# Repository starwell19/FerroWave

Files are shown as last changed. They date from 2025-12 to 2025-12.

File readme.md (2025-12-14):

# FerroWave

Audio-reactive **ferrofluid visualizer** built on **ESP32-A1S (ES8388)**.  
Streams Bluetooth audio (A2DP) or AUX input into the on-board codec, extracts live envelopes, and drives:

* a **coil + MOSFET trigger module** (PWM on GPIO 22) for ferrofluid motion
* a **WS2812B LED ring** (GPIO 23) for synced visuals
* **Six onboard buttons** for live preset control (no computer needed!)

> Created by **Makarov87** and **crowdfunded by the MakerWorld community**.  

**Crowdfunding Campaign:** https://makerworld.com/en/crowdfunding/70-ferrowave

---

## Acknowledgments

**This project was made possible by the MakerWorld community!**

FerroWave was successfully crowdfunded on MakerWorld, and it would not exist without the support, belief, and contributions of backers and makers from around the world.

**Special thanks to:**
- All MakerWorld backers who supported this campaign
- The MakerWorld platform for enabling maker-driven innovation
- Every contributor who helped bring this vision to life
- The open-source community for incredible libraries and tools

**Your support made this dream a reality. Thank you!** 🙏

---

## Project Status (AUX + Button Control Edition)

This repo reflects the **latest "AUX + Button Control Edition"** firmware with the finalized hardware layout.

**What's new in this version:**

* **AUX Input Support**: Auto-detects when 3.5mm cable is plugged in and switches from Bluetooth
* **Physical Button Controls**: Six onboard buttons for live control without serial/computer
  + Cycle through magnet modes (8 presets)
  + Cycle through LED effects (10 modes)
  + Switch between EQ presets (8 audio profiles)
* **Dual Input**: Seamlessly switch between Bluetooth and AUX input
* **Non-blocking performance**: Fixed audio stuttering issues for smooth playback

**Previous improvements:**

* Switched to **4x18650 battery pack** with breadboard power distribution:
  + Portable, cordless operation
  + Clean 5V rail for all components
  + 1-1.5 hours runtime typical
  + Simple, no voltage converters needed
* Low-side **MOSFET trigger module** (AOD4184-style):
  + Built-in flyback diode + status LED
  + 3.3 V logic input, 5V coil output
  + Much more maker-friendly than raw MOSFET wiring
* Finalized **pinout** to avoid conflicts with ES8388 codec and onboard buttons:
  + GPIO 22 → **MOSFET gate** (coil PWM)
  + GPIO 23 → **WS2812B LED DIN**
  + ES8388 on standard I²S pins (27 / 25 / 26 / 35 / 0)

---

## Table of Contents

* [Features](#features)
* [Hardware](#hardware)
* [Button Controls](#button-controls)
* [Wiring](#wiring-quick-reference)
* [Power](#power-4x18650-battery-system)
* [Pinout](#pinout)
* [Firmware Setup](#firmware-setup-arduino-ide)
* [Required Libraries](#required-libraries)
* [Build & Upload](#build--upload)
* [Serial Commands](#serial-tuning-panel)
* [How to Use](#how-to-use)
* [Troubleshooting](#troubleshooting)
* [Contributing](#contributing)
* [License](#license)

---

## Features

* **Dual Input Sources**:
  + **Bluetooth A2DP sink** for wireless audio
  + **AUX/Line-In** with auto-detection (switches when cable is plugged in)
* **Six Physical Buttons** for standalone operation:
  + Cycle magnet modes (up/down)
  + Cycle LED effects (up/down)
  + Switch EQ presets (up/down)
* **8 Magnet Behavior Modes**:
  + SMOOTH, SPIKE, BOUNCE, CHAOS, PULSE, WAVE, TREMOLO, BREATH
* **10 LED Visual Effects**:
  + Rainbow, Spectrum, VU-Meter, Pulse, Bass Glow, Fire, Ocean, Strobe, Chase, Sparkle
* **8 EQ Presets**:
  + Flat, Bass Boost, Treble, Vocal, Rock, Electronic, Jazz, Classical
* **Magnet control** via LEDC **PWM** on GPIO 22 with:
  + Adjustable frequency (1-5000 Hz)
  + Tunable duty window and sensitivity
  + Real-time envelope followers
* **Serial tuning panel** for advanced control:
  + Live parameter adjustment
  + Test pulses and diagnostics
  + Status readouts
* Designed to be **stable on ESP32 core 2.0.14+**

---

## Hardware

### Required Components

* **ESP32-A1S / ESP32-Audio-Kit v2.2** (with **ES8388** codec)
* **WS2812B LED ring** (24 LEDs recommended)
* **Low-side MOSFET trigger module** (AOD4184 or similar)
* **Electromagnet** (5V, 1-2A)
* **4x18650 Battery Pack** with 5V output
* **Breadboard Power Module**
* **Ferrofluid display container**

See [docs/BOM.md](docs/BOM.md) for complete bill of materials.

---

## Button Controls

| Button | GPIO | Function | Action |
|---|---|---|---|
| **Button 1** | GPIO 36 | Magnet Mode | Cycle UP through 8 modes |
| **Button 2** | GPIO 39 | Magnet Mode | Cycle DOWN through 8 modes |
| **Button 3** | GPIO 34 | LED Effect | Cycle UP through 10 effects |
| **Button 4** | GPIO 35 | LED Effect | Cycle DOWN through 10 effects |
| **Button 5** | GPIO 32 | EQ Preset | Cycle UP through 8 presets |
| **Button 6** | GPIO 33 | EQ Preset | Cycle DOWN through 8 presets |

---

## Wiring (quick reference)

```
4x18650 Battery Pack (5V Output)
         |
    Power Switch
         |
  Breadboard Power Module
    (+ and - rails)
         |
         ├──> ESP32-A1S (5V + GND)
         ├──> LED Ring (5V + GND)
         └──> Electromagnet + (5V)

LED Ring DIN ──> GPIO 23 (through 330Ω resistor)
ESP32 GPIO 22 ──> MOSFET Gate
```

See [docs/WIRING.md](docs/WIRING.md) for complete instructions.

---

## Power (4x18650 Battery System)

* **Portable operation** with rechargeable batteries
* **1-1.5 hours** typical runtime
* **2-4A** typical draw, up to 5A peak
* Uses quality protected 18650 cells (Samsung, LG, Sony, Panasonic)

---

## Pinout

**Control:**
* GPIO 22 → MOSFET gate (PWM)
* GPIO 23 → LED ring DIN

**Buttons:**
* GPIO 36, 39, 34, 35, 32, 33 (built-in)

**I²S Audio:**
* GPIO 27 → BCK
* GPIO 25 → WS
* GPIO 26 → DATA_OUT

---

## Firmware Setup (Arduino IDE)

1. Install **ESP32 board support** (v2.0.14+)
2. Select **"ESP32 Dev Module"**
3. Install required libraries (see below)
4. Upload firmware
5. Connect via Bluetooth or AUX

---

## Required Libraries

Install via Arduino Library Manager:

1. **AudioTools** by pschatzmann
2. **ESP32-A2DP** by pschatzmann
3. **Adafruit NeoPixel** by Adafruit

See [docs/LIBRARIES.md](docs/LIBRARIES.md) for detailed installation.

---

## Build & Upload

1. Clone repository
2. Open `.ino` file in Arduino IDE
3. Select COM port
4. Press **Upload**
5. Open Serial Monitor (115200 baud)
6. Connect and play music!

---

## Serial Tuning Panel

**Magnet Modes (1-8):**
```
1=SMOOTH  2=SPIKE  3=BOUNCE  4=CHAOS
5=PULSE   6=WAVE   7=TREMOLO 8=BREATH
```

**LED Modes (c1-c10):**
```
c1=Rainbow  c2=Spectrum  c3=Pulse    c4=VU-Meter  c5=Bass Glow
c6=Fire     c7=Ocean     c8=Strobe   c9=Chase     c10=Sparkle
```

**Parameters:**
```
f<num> = PWM frequency    s<num> = Sensitivity
a<num> = Attack speed     r<num> = Release speed
d<num> = Max duty         b<num> = Base duty
p<num> = Spike intensity  l<num> = LED brightness
v<num> = Volume
```

**Utilities:**
```
? = Show settings    t = Test pulse
m = List modes       n = List LED modes
aux = Switch to AUX  bt = Switch to Bluetooth
```

See [commands.md](commands.md) for complete reference.

---

## How to Use

### Standalone (No Computer)
1. Power on
2. Connect Bluetooth or plug AUX cable
3. Play music
4. Use buttons to control presets

### Advanced (Serial Monitor)
1. Connect USB
2. Open Serial Monitor (115200 baud)
3. Use commands for fine tuning
4. Type `?` for current settings

---

## Troubleshooting

**No power?** Check battery charge and connections  
**No audio?** Verify Bluetooth pairing or AUX cable  
**Coil not working?** Test with `t` command  
**LEDs dark?** Try `l255` and check GPIO 23

See [docs/TROUBLESHOOTING.md](docs/TROUBLESHOOTING.md) for complete guide.

---

## Contributing

Contributions welcome! See [CONTRIBUTING.md](CONTRIBUTING.md) for guidelines.

**This project was crowdfunded by the MakerWorld community!**

---

## Community & Support

* **Issues**: [GitHub Issues](https://github.com/matoslav/FerroWave/issues)
* **Discussions**: [GitHub Discussions](https://github.com/matoslav/FerroWave/discussions)
* **MakerWorld**: https://makerworld.com/en/crowdfunding/70-ferrowave

If you want to support me and my FerroWave development, you can buy me a coffee at: https://ko-fi.com/makarov87

---

## Credits

**Created by**: Makarov87  
**Crowdfunded by**: MakerWorld Community

**Libraries:**
* [AudioTools](https://github.com/pschatzmann/arduino-audio-tools) by pschatzmann
* [ESP32-A2DP](https://github.com/pschatzmann/ESP32-A2DP) by pschatzmann
* [Adafruit NeoPixel](https://github.com/adafruit/Adafruit_NeoPixel) by Adafruit

**Special Thanks:**
* All MakerWorld backers
* Open-source Arduino and ESP32 communities
* Everyone who contributed ideas and feedback

---

## License

MIT License - See [LICENSE](LICENSE) file.

**Author**: Makarov87  
**Crowdfunded by**: MakerWorld Community

When using or modifying FerroWave:
- Credit Makarov87
- Link to https://github.com/matoslav/FerroWave
- Acknowledge MakerWorld crowdfunding

---

**Created by Makarov87**  
**Crowdfunded by the MakerWorld Community**  
**Built with ❤️ and ferrofluid**

Thank you to all MakerWorld backers! 🙏

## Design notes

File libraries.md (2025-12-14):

# FerroWave DIY Build Guide
## Required Libraries & Installation

### Hardware Requirements
- **ESP32-A1S Audio Kit v2.2** (with ES8388 codec)
- **5V Electromagnet** (controlled via MOSFET)
- **WS2812B LED Ring** (24 LEDs)
- **MOSFET** (e.g., IRLZ44N or similar logic-level N-channel)
- **330Ω Resistor** (for LED data line)
- **Ferrofluid** in display container
- Power supply (5V for LEDs and magnet)

---

## Arduino IDE Setup

### 1. ESP32 Board Support
Install ESP32 board support in Arduino IDE:

**Via Board Manager:**
1. Open Arduino IDE
2. Go to `File` → `Preferences`
3. Add to "Additional Board URLs":
   ```
   https://espressif.github.io/arduino-esp32/package_esp32_index.json
   ```
4. Go to `Tools` → `Board` → `Boards Manager`
5. Search for "ESP32" and install **"esp32" by Espressif Systems**
6. Select Board: `Tools` → `Board` → `ESP32 Arduino` → `ESP32 Dev Module`

---

## Required Libraries

### 1. **AudioTools** (by Phil Schatzmann)
**Primary audio processing library**

**Installation:**
- Arduino IDE: `Sketch` → `Include Library` → `Manage Libraries`
- Search: "AudioTools"
- Install: **"AudioTools" by pschatzmann**
- Version: Latest (tested with v0.9.x)

**GitHub:** https://github.com/pschatzmann/arduino-audio-tools

**What it does:**
- Handles I2S audio streams
- Provides AudioBoardStream for ES8388 codec
- Ring buffer for audio processing
- Multi-output routing (Bluetooth + processing)

---

### 2. **ESP32-A2DP** (by Phil Schatzmann)
**Bluetooth A2DP audio sink**

**Installation:**
- Arduino IDE: `Sketch` → `Include Library` → `Manage Libraries`
- Search: "ESP32-A2DP"
- Install: **"ESP32-A2DP" by pschatzmann**
- Version: Latest (tested with v1.7.x)

**GitHub:** https://github.com/pschatzmann/ESP32-A2DP

**What it does:**
- Enables Bluetooth audio receiver functionality
- A2DP profile support (wireless audio streaming)
- Integrates with AudioTools for audio routing

---

### 3. **Adafruit NeoPixel**
**WS2812B LED control**

**Installation:**
- Arduino IDE: `Sketch` → `Include Library` → `Manage Libraries`
- Search: "Adafruit NeoPixel"
- Install: **"Adafruit NeoPixel" by Adafruit**
- Version: Latest (tested with v1.11.x)

**GitHub:** https://github.com/adafruit/Adafruit_NeoPixel

**What it does:**
- Controls WS2812B addressable RGB LEDs
- Handles color calculations and LED timing
- Provides easy color and brightness control

---

## Complete Library Installation Summary

### Option 1: Arduino Library Manager (Recommended)
```
1. Sketch → Include Library → Manage Libraries
2. Search and install each:
   - "AudioTools" by pschatzmann
   - "ESP32-A2DP" by pschatzmann
   - "Adafruit NeoPixel" by Adafruit
```

### Option 2: Manual Installation (Advanced)
Clone repositories into your Arduino `libraries` folder:

```bash
cd ~/Documents/Arduino/libraries/

# AudioTools
git clone https://github.com/pschatzmann/arduino-audio-tools.git

# ESP32-A2DP
git clone https://github.com/pschatzmann/ESP32-A2DP.git

# Adafruit NeoPixel
git clone https://github.com/adafruit/Adafruit_NeoPixel.git
```

Then restart Arduino IDE.

---

## Wiring Diagram

### ESP32-A1S Connections

**Electromagnet (via MOSFET):**
- MOSFET Gate → GPIO 22
- MOSFET Drain → Electromagnet (-)
- MOSFET Source → GND
- Electromagnet (+) → 5V Power Supply

**LED Ring (WS2812B):**
- LED DIN → GPIO 23 (through 330Ω resistor)
- LED VCC → 5V
- LED GND → GND

**Onboard Buttons (ESP32-A1S):**
- Button 1: GPIO 36 (Magnet Mode ↑)
- Button 2: GPIO 39 (Magnet Mode ↓)
- Button 3: GPIO 34 (LED Mode ↑)
- Button 4: GPIO 35 (LED Mode ↓)
- Button 5: GPIO 32 (EQ Preset ↑)
- Button 6: GPIO 33 (EQ Preset ↓)

**I2S Audio (Pre-wired on ESP32-A1S):**
- BCK: GPIO 27
- WS: GPIO 25
- DATA OUT: GPIO 26
- DATA IN (AUX): GPIO 35
- MCLK: GPIO 0

---

## Upload Settings

**Board Settings in Arduino IDE:**
```
Board: "ESP32 Dev Module"
Upload Speed: 921600
CPU Frequency: 240MHz
Flash Frequency: 80MHz
Flash Mode: QIO
Flash Size: 4MB (32Mb)
Partition Scheme: "Default 4MB with spiffs"
Core Debug Level: "None"
PSRAM: "Disabled"
```

**Port:** Select your ESP32's COM/USB port

---

## Compilation Notes

### Expected Memory Usage
- Sketch uses approximately **~65-75%** of program storage
- Global variables use approximately **~25-30%** of dynamic memory
- Uses ESP32 dual-core capabilities for audio processing

### Common Compilation Issues

**1. "AudioSource is ambiguous"**
- Fixed in code (renamed enum to `InputSource`)
- Caused by naming conflict with AudioTools library

**2. Missing library errors**
- Ensure all three libraries are installed
- Restart Arduino IDE after installation

**3. "Bluetooth: Cannot allocate memory"**
- Set partition scheme to "Default 4MB with spiffs"
- Ensure no other large libraries are included

---

## First Boot Checklist

1. **Serial Monitor** (115200 baud)
   - Should show startup banner
   - Lists all button controls
   - Shows current settings

2. **LED Ring Test**
   - Blue startup animation on power-up
   - Should respond to audio input

3. **Bluetooth Pairing**
   - Device name: "FerroWave_AUX"
   - Should appear in Bluetooth device list
   - No pairing code required

4. **Test Commands**
   - Type `?` in Serial Monitor to see settings
   - Type `t` to test electromagnet pulse
   - Type `m` to list magnet modes

---

## Troubleshooting

### No Audio Output
- Check I2S wiring (BCK, WS, DATA pins)
- Verify AudioBoardStream configuration
- Ensure ES8388 codec is properly initialized

### LEDs Not Working
- Verify LED power (5V, GND)
- Check data pin (GPIO 23) connection
- Ensure 330Ω resistor is in place
- Try reducing LED brightness: `l50` in serial

### Electromagnet Not Responding
- Check MOSFET wiring
- Verify GPIO 22 connection
- Test with `t` command in serial monitor
- Check power supply capacity

### Bluetooth Won't Connect
- Restart ESP32
- Ensure no other device is connected
- Check if Bluetooth is enabled on source device
- Try forgetting device and re-pairing

---

## Power Requirements

- **ESP32-A1S Board:** ~500mA (via USB or 5V)
- **LED Ring (24 LEDs):** Up to 1.4A at full brightness white
- **Electromagnet:** 500mA - 2A depending on coil

**Recommended:** 5V 3A+ power supply for stable operation

---

## Additional Resources

- **AudioTools Documentation:** https://github.com/pschatzmann/arduino-audio-tools/wiki
- **ESP32-A2DP Examples:** https://github.com/pschatzmann/ESP32-A2DP/tree/main/examples
- **NeoPixel Guide:** https://learn.adafruit.com/adafruit-neopixel-uberguide

---

## License & Credits

- **FerroWave:** DIY ferrofluid visualizer project
- **Libraries:** See individual library licenses
  - AudioTools: GPL-3.0
  - ESP32-A2DP: Apache-2.0
  - Adafruit NeoPixel: LGPL-3.0

---

**Version:** 1.0 (AUX + Button Control Edition)  
**Last Updated:** December 2024

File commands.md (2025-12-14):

# FerroWave Serial Commands Reference

Complete command reference for controlling FerroWave via Serial Monitor (115200 baud).

> **Note:** Physical buttons provide quick access to presets. Serial commands are for advanced tuning and diagnostics.

---

## Quick Reference

| Command | Function | Example |
|---|---|---|
| `1-8` | Select magnet mode | `3` |
| `c1-c10` | Select LED mode | `c7` |
| `f<num>` | Set PWM frequency | `f500` |
| `s<num>` | Set sensitivity | `s120` |
| `a<num>` | Set attack speed | `a80` |
| `r<num>` | Set release speed | `r40` |
| `d<num>` | Set max duty | `d85` |
| `b<num>` | Set base duty | `b20` |
| `p<num>` | Set spike intensity | `p70` |
| `l<num>` | Set LED brightness | `l150` |
| `v<num>` | Set volume | `v75` |
| `aux` | Switch to AUX input | `aux` |
| `bt` | Switch to Bluetooth | `bt` |
| `?` | Show current settings | `?` |
| `t` | Test pulse | `t` |
| `m` | List magnet modes | `m` |
| `n` | List LED modes | `n` |

---

## Magnet Mode Selection

**Syntax:** Single digit `1-8`

| Command | Mode | Description | Characteristics |
|---|---|---|---|
| `1` | SMOOTH | Gentle flowing waves | Slow, graceful, relaxed |
| `2` | SPIKE | Sharp transients | Emphasizes beats, spiky |
| `3` | BOUNCE | Rhythmic pumping | Follows groove, bouncy |
| `4` | CHAOS | Aggressive random | Unpredictable, maximum power |
| `5` | PULSE | Beat-synced pulses | Distinct on/off, percussive |
| `6` | WAVE | Building surges | Slow accumulation, dramatic |
| `7` | TREMOLO | Rapid flutter | Vibrato effect, rapid |
| `8` | BREATH | Meditative breathing | Very slow, calming |

**Example:**
```
> 2
Mode -> SPIKE
```

---

## LED Mode Selection

**Syntax:** `c<number>` where number is 1-10

| Command | Mode | Description | Effect Type |
|---|---|---|---|
| `c1` | Rainbow | Spinning rainbow wheel | Color cycle |
| `c2` | Spectrum | Bar graph analyzer | Audio reactive |
| `c3` | Pulse | Blue breathing effect | Single color pulse |
| `c4` | VU-Meter | Center-split meter | Audio level |
| `c5` | Bass Glow | Red bass intensity | Audio reactive |
| `c6` | Fire | Flickering flames | Animated |
| `c7` | Ocean | Blue-green waves | Animated |
| `c8` | Strobe | White flash on peaks | Audio reactive |
| `c9` | Chase | Three colored dots | Animated |
| `c10` | Sparkle | Random twinkling | Animated |

**Example:**
```
> c7
LED mode -> Ocean
```

---

## Tuning Parameters

### PWM Frequency (`f`)

**Syntax:** `f<number>`  
**Range:** 1-5000 Hz  
**Default:** 4 Hz

Controls how fast the electromagnet pulses.

**Recommended ranges:**
- `f2-f10`: Slow, visible pulsing (dramatic movement)
- `f50-f500`: Mid-range smooth control
- `f1000-f2000`: Very fast, near-continuous force

**Examples:**
```
> f4
PWM frequency -> 4.0 Hz

> f500
PWM frequency -> 500.0 Hz

> f1000
PWM frequency -> 1000.0 Hz
```

---

### Sensitivity (`s`)

**Syntax:** `s<number>`  
**Range:** 0-200%  
**Default:** 100%

Controls how strongly audio input affects the magnet.

**Guide:**
- `s50`: Subtle, requires loud music
- `s100`: Default, balanced
- `s150`: Sensitive, reacts to small changes
- `s200`: Maximum sensitivity

**Examples:**
```
> s120
Sensitivity -> 120%

> s80
Sensitivity -> 80%
```

---

### Attack Speed (`a`)

**Syntax:** `a<number>`  
**Range:** 0-100  
**Default:** 60

How fast the magnet responds to increasing audio levels.

**Guide:**
- `a10-a40`: Slow, smooth response
- `a50-a70`: Musical, natural
- `a80-a100`: Snappy, percussive

**Examples:**
```
> a85
Attack speed -> 85/100

> a30
Attack speed -> 30/100
```

---

### Release Speed (`r`)

**Syntax:** `r<number>`  
**Range:** 0-100  
**Default:** 30

How fast the magnet relaxes when audio decreases.

**Guide:**
- `r10-r30`: Slow decay, sustained
- `r40-r60`: Moderate release
- `r70-r100`: Fast drop, tight

**Examples:**
```
> r50
Release speed -> 50/100

> r20
Release speed -> 20/100
```

---

### Max Duty (`d`)

**Syntax:** `d<number>`  
**Range:** 10-100%  
**Default:** 80%

Maximum power ceiling for electromagnet (safety limit).

**Guide:**
- `d60-d80`: Safe, conservative
- `d85-d95`: Higher power (watch temperature)
- `d100`: Maximum (only with adequate cooling)

⚠️ **Warning:** Higher values generate more heat. Monitor coil temperature!

**Examples:**
```
> d75
Max duty -> 75%

> d90
Max duty -> 90%
```

---

### Base Duty (`b`)

**Syntax:** `b<number>`  
**Range:** 0-50%  
**Default:** 15%

Minimum always-on power (baseline magnetic field).

**Guide:**
- `b0`: Off when silent (dynamic range)
- `b10-b20`: Gentle constant field
- `b30-b50`: Strong baseline (less dynamic)

**Examples:**
```
> b20
Base duty -> 20%

> b5
Base duty -> 5%
```

---

### Spike Intensity (`p`)

**Syntax:** `p<number>`  
**Range:** 0-100  
**Default:** 50

Extra boost for SPIKE and transient-heavy modes.

**Guide:**
- `p30-p50`: Moderate emphasis
- `p60-p80`: Strong spikes
- `p90-p100`: Maximum aggression

**Examples:**
```
> p75
Spike intensity -> 75/100

> p40
Spike intensity -> 40/100
```

---

### LED Brightness (`l`)

**Syntax:** `l<number>`  
**Range:** 0-255  
**Default:** 100

LED ring brightness level.

**Guide:**
- `l50`: Dim (power saving)
- `l100`: Default
- `l150`: Bright
- `l255`: Maximum

**Examples:**
```
> l180
LED brightness -> 180/255

> l60
LED brightness -> 60/255
```

---

### Volume (`v`)

**Syntax:** `v<number>`  
**Range:** 0-100%  
**Default:** 80%

Audio output volume level.

**Examples:**
```
> v75
Volume -> 75%

> v90
Volume -> 90%
```

---

## Audio Source Control

### Switch to AUX Input

**Syntax:** `aux`

Manually switch to 3.5mm AUX line input.

```
> aux
Switching to AUX input...
AUX input active
```

---

### Switch to Bluetooth

**Syntax:** `bt`

Manually switch to Bluetooth A2DP input.

```
> bt
Switching to Bluetooth...
Bluetooth active
```

> **Note:** AUX input auto-switches when cable is detected. These commands allow manual override.

---

## Utility Commands

### Show Current Settings (`?`)

**Syntax:** `?`

Displays all current parameter values and modes.

```
> ?

========== CURRENT SETTINGS ==========
Audio Source:    Bluetooth
Magnet Mode:     SPIKE
PWM Frequency:   4.0 Hz
Sensitivity:     120%
Attack Speed:    85/100
Release Speed:   40/100
Max Duty:        80%
Base Duty:       15%
Spike Intensity: 75/100
Volume:          80%
EQ Preset:       Bass Boost
Bass EQ:         +6
Treble EQ:       -2
LED Brightness:  100/255
LED Mode:        Fire
======================================
```

---

### Test Pulse (`t`)

**Syntax:** `t`

Triggers a 2-second full-power test pulse with LED flash.

Useful for:
- Testing electromagnet wiring
- Verifying MOSFET functionality
- Checking power supply capacity

```
> t
TEST PULSE: 2 seconds at max...
Test complete.
```

---

### List Magnet Modes (`m`)

**Syntax:** `m`

Displays all available magnet modes.

```
> m

========== MAGNET MODES ==========
1 = SMOOTH  - Gentle flowing waves
2 = SPIKE   - Sharp transients, spiky
3 = BOUNCE  - Rhythmic pumping
4 = CHAOS   - Aggressive, unpredictable
5 = PULSE   - Distinct on/off beats
6 = WAVE    - Slow building surges
7 = TREMOLO - Rapid flutter effect
8 = BREATH  - Slow meditative breathing
==================================
```

---

### List LED Modes (`n`)

**Syntax:** `n`

Displays all available LED effects.

```
> n

========== LED MODES ==========
c1  = Rainbow spin
c2  = Spectrum analyzer
c3  = Pulse (blue)
c4  = VU-Meter
c5  = Bass glow (red)
c6  = Fire effect
c7  = Ocean waves
c8  = Strobe flash
c9  = Color chase
c10 = Sparkle
===============================
```

---

## Preset Recipes

### Quick-Start Presets

Copy and paste these command sequences for instant presets:

#### 🎉 Party Mode
```
2
c8
f4
s150
a90
r40
p80
l200
```

#### 🌊 Chill Mode
```
8
c7
f2
s60
a30
r20
l100
```

#### 💃 Dance Mode
```
3
c2
f10
s120
a80
r60
l150
```

#### 🔥 Fire Show
```
4
c6
f500
s140
a85
d90
l180
```

---

## Tips & Best Practices

### For Experimentation
1. Start with `?` to see current settings
2. Change one parameter at a time
3. Use `t` to verify electromagnet response
4. Watch Serial output for real-time feedback

### For Performance
1. Set your desired mode (`1-8`)
2. Set LED effect (`c1-c10`)
3. Fine-tune sensitivity (`s`) first
4. Adjust attack/release (`a`, `r`) for feel
5. Set PWM frequency (`f`) for desired motion style

### For Safety
1. Always start with `d80` or lower
2. Monitor coil temperature when increasing `d`
3. Use `b` to set a safe baseline
4. Test with `t` before live performance

---

## Troubleshooting Commands

### Magnet not responding?
```
> t          # Test pulse
> d90        # Increase max duty
> s150       # Increase sensitivity
> b20        # Add baseline field
```

### Too aggressive?
```
> s80        # Reduce sensitivity
> d70        # Lower power ceiling
> a40        # Slow attack
> r30        # Slow release
```

### LEDs too dim?
```
> l200       # Increase brightness
> c1         # Try rainbow (brightest)
```

### Audio source issues?
```
> aux        # Switch to AUX
> bt         # Switch to Bluetooth
> v80        # Adjust volume
```

---

**For physical button controls, see the main README.md**

---

*Part of the [FerroWave](https://github.com/matoslav/FerroWave) project by Makarov87*

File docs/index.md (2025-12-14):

# FerroWave Documentation

Welcome to the FerroWave documentation! This index will help you find the information you need.

**Project**: FerroWave - Audio-Reactive Ferrofluid Visualizer  
**Author**: Makarov87  
**Crowdfunded by**: [MakerWorld Community](https://makerworld.com/en/crowdfunding/70-ferrowave)  
**License**: MIT

---

## Quick Links

- **[Main Repository](https://github.com/matoslav/FerroWave)** - GitHub repository
- **[MakerWorld Campaign](https://makerworld.com/en/crowdfunding/70-ferrowave)** - Crowdfunding page
- **[Issues](https://github.com/matoslav/FerroWave/issues)** - Report bugs or request features
- **[Discussions](https://github.com/matoslav/FerroWave/discussions)** - Community discussion

---

## 📚 Documentation

### Getting Started

Start here if you're new to FerroWave:

1. **[README.md](../README.md)** - Project overview, features, and quick start
2. **[BOM.md](BOM.md)** - Complete bill of materials and shopping guide
3. **[LIBRARIES.md](LIBRARIES.md)** - Required Arduino libraries installation
4. **[WIRING.md](WIRING.md)** - Step-by-step wiring instructions

### Building & Programming

Follow these guides to build and program your FerroWave:

- **[WIRING.md](WIRING.md)** - Complete wiring guide with diagrams
  - Power system setup (4x18650 battery)
  - ESP32-A1S connections
  - Electromagnet circuit
  - LED ring wiring
  - Step-by-step assembly

- **[LIBRARIES.md](LIBRARIES.md)** - Library installation
  - Arduino IDE setup
  - ESP32 board support
  - Required libraries (AudioTools, ESP32-A2DP, NeoPixel)
  - Compilation settings

### Using FerroWave

Learn how to operate and customize:

- **[commands.md](../commands.md)** - Serial command reference
  - Magnet modes (1-8)
  - LED effects (c1-c10)
  - Tuning parameters
  - Audio source control
  - Preset recipes

- **[README.md](../README.md)** - Usage guide
  - Button controls
  - EQ presets
  - Recommended settings
  - Performance tips

### Troubleshooting & Support

Having issues? Check here:

- **[TROUBLESHOOTING.md](TROUBLESHOOTING.md)** - Comprehensive troubleshooting
  - Power issues
  - Compilation errors
  - Upload problems
  - Audio issues
  - Electromagnet problems
  - LED issues
  - Battery problems

### Contributing

Want to contribute to FerroWave?

- **[CONTRIBUTING.md](../CONTRIBUTING.md)** - Contribution guidelines
  - How to contribute
  - Code style guidelines
  - Development workflow
  - Community guidelines

- **[CHANGELOG.md](../CHANGELOG.md)** - Version history and roadmap

### Legal

- **[LICENSE](../LICENSE)** - MIT License with attribution requirements

---

## 📖 Document Overview

### Main Documents (Root Level)

| Document | Description | Audience |
|---|---|---|
| [README.md](../README.md) | Main project documentation | Everyone |
| [LICENSE](../LICENSE) | MIT License & attribution | Everyone |
| [CHANGELOG.md](../CHANGELOG.md) | Version history | Developers |
| [CONTRIBUTING.md](../CONTRIBUTING.md) | How to contribute | Contributors |
| [commands.md](../commands.md) | Serial command reference | Users |

### Documentation Folder (docs/)

| Document | Description | Audience |
|---|---|---|
| [BOM.md](BOM.md) | Bill of materials | Builders |
| [LIBRARIES.md](LIBRARIES.md) | Library installation | Builders |
| [WIRING.md](WIRING.md) | Wiring instructions | Builders |
| [TROUBLESHOOTING.md](TROUBLESHOOTING.md) | Problem solving | Users |
| [index.md](index.md) | This document | Everyone |

---

## 🚀 Quick Start Guide

### For First-Time Builders

1. Read [README.md](../README.md) for project overview
2. Check [BOM.md](BOM.md) and order parts
3. Install libraries following [LIBRARIES.md](LIBRARIES.md)
4. Wire components using [WIRING.md](WIRING.md)
5. Upload firmware from `/firmware` folder
6. Learn commands from [commands.md](../commands.md)

### For Existing Users

1. Check [commands.md](../commands.md) for serial commands
2. Use [TROUBLESHOOTING.md](TROUBLESHOOTING.md) if issues arise
3. See [CHANGELOG.md](../CHANGELOG.md) for updates

### For Contributors

1. Read [CONTRIBUTING.md](../CONTRIBUTING.md)
2. Check [CHANGELOG.md](../CHANGELOG.md) for roadmap
3. Review existing issues and discussions

---

## 🎯 Features by Document

### Hardware Information
- **BOM.md** - What to buy
- **WIRING.md** - How to connect
- **TROUBLESHOOTING.md** - Hardware issues

### Software Information
- **LIBRARIES.md** - What to install
- **commands.md** - How to control
- **TROUBLESHOOTING.md** - Software issues

### Project Information
- **README.md** - Overview & features
- **CHANGELOG.md** - Version history
- **CONTRIBUTING.md** - How to help
- **LICENSE** - Legal terms

---

## 🔧 By Skill Level

### Beginner
Start with these documents:
1. [README.md](../README.md)
2. [BOM.md](BOM.md)
3. [LIBRARIES.md](LIBRARIES.md)
4. [WIRING.md](WIRING.md)

### Intermediate
You might need:
- [commands.md](../commands.md) - For advanced tuning
- [TROUBLESHOOTING.md](TROUBLESHOOTING.md) - When issues arise

### Advanced
Dive deeper:
- [CONTRIBUTING.md](../CONTRIBUTING.md) - Add features
- [CHANGELOG.md](../CHANGELOG.md) - See roadmap
- Source code in `/firmware`

---

## 🎨 By Task

### I want to build FerroWave
1. [BOM.md](BOM.md) - Shopping list
2. [LIBRARIES.md](LIBRARIES.md) - Software setup
3. [WIRING.md](WIRING.md) - Assembly guide

### I want to use FerroWave
1. [README.md](../README.md) - Basic operation
2. [commands.md](../commands.md) - Serial commands
3. Button controls (in README.md)

### I want to modify FerroWave
1. [CONTRIBUTING.md](../CONTRIBUTING.md) - Guidelines
2. [commands.md](../commands.md) - Parameter reference
3. Source code in `/firmware`

### I'm having problems
1. [TROUBLESHOOTING.md](TROUBLESHOOTING.md) - Problem solving
2. Check [GitHub Issues](https://github.com/matoslav/FerroWave/issues)
3. Ask in [Discussions](https://github.com/matoslav/FerroWave/discussions)

---

## 📦 Repository Structure

```
FerroWave/
├── README.md                 # Main documentation
├── LICENSE                   # MIT License
├── CHANGELOG.md             # Version history
├── CONTRIBUTING.md          # Contribution guide
├── commands.md              # Serial commands
├── docs/                    # Documentation folder
│   ├── index.md            # This file
│   ├── BOM.md              # Bill of materials
│   ├── LIBRARIES.md        # Library installation
│   ├── WIRING.md           # Wiring guide
│   └── TROUBLESHOOTING.md  # Troubleshooting
├── firmware/               # Arduino firmware
│   └── FerroWave.ino      # Main sketch
└── hardware/              # (Planned) Schematics
```

---

## 💡 Tips for Using This Documentation

### Search Tips
- Use Ctrl+F (or Cmd+F) to search within documents
- Check the table of contents in each document
- Look for related sections at document ends

### Navigation Tips
- Use the [Quick Links](#quick-links) section for common tasks
- Browse by [Skill Level](#-by-skill-level) if you're new
- Use [By Task](#-by-task) for specific goals

### Getting Help
1. Search existing documentation first
2. Check [TROUBLESHOOTING.md](TROUBLESHOOTING.md)
3. Search [GitHub Issues](https://github.com/matoslav/FerroWave/issues)
4. Ask in [GitHub Discussions](https://github.com/matoslav/FerroWave/discussions)
5. Create new issue if needed

---

## 🌟 Special Thanks

**This project was made possible by the MakerWorld community through crowdfunding.**

Thank you to:
- All MakerWorld backers
- The open-source Arduino and ESP32 communities
- Contributors and testers
- Everyone who provided feedback and support

**[Support the campaign](https://makerworld.com/en/crowdfunding/70-ferrowave)** | **[Star on GitHub](https://github.com/matoslav/FerroWave)**

---

## 📝 Documentation Updates

This documentation is maintained alongside the FerroWave project. If you find errors or have suggestions:

1. Check if issue already exists
2. Create an [issue](https://github.com/matoslav/FerroWave/issues) describing the problem
3. Or submit a pull request with corrections

See [CONTRIBUTING.md](../CONTRIBUTING.md) for guidelines.

---

## 🔗 External Resources

### Hardware
- [ESP32-A1S Documentation](https://docs.ai-thinker.com/)
- [WS2812B Datasheet](https://cdn-shop.adafruit.com/datasheets/WS2812B.pdf)
- [18650 Battery Guide](https://batteryuniversity.com/)

### Software Libraries
- [AudioTools GitHub](https://github.com/pschatzmann/arduino-audio-tools)
- [ESP32-A2DP GitHub](https://github.com/pschatzmann/ESP32-A2DP)
- [Adafruit NeoPixel Guide](https://learn.adafruit.com/adafruit-neopixel-uberguide)

### Community
- [MakerWorld Platform](https://makerworld.com/)
- [Arduino Forum](https://forum.arduino.cc/)
- [ESP32 Community](https://www.esp32.com/)

---

**Last Updated**: December 2024  
**Documentation Version**: 2.0  
**Project**: [FerroWave](https://github.com/matoslav/FerroWave)  
**Author**: Makarov87  
**License**: MIT

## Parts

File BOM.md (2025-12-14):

# FerroWave Bill of Materials (BOM)

Complete list of parts needed to build FerroWave.

**Project**: FerroWave - Ferrofluid Visualizer  
**Author**: Makarov87  
**Crowdfunded by**: MakerWorld Community  
**Version**: 2.0 (Battery-Powered Edition)

---

## Quick Summary

| Category | Estimated Cost | Notes |
|---|---|---|
| Electronics | $40-60 USD | Main components |
| Power System | $15-25 USD | Batteries and holder |
| Hardware/Misc | $10-20 USD | Wires, resistors, connectors |
| **Total** | **$65-105 USD** | Excluding ferrofluid & display |

*Prices approximate, may vary by region and supplier*

---

## Essential Components

### Microcontroller & Audio

| Item | Specification | Quantity | Est. Price | Source | Notes |
|---|---|---|---|---|---|
| ESP32-A1S Audio Kit v2.2 | With ES8388 codec | 1 | $15-25 | AliExpress, Amazon | Must be v2.2 or compatible |
| Micro USB Cable | Data capable | 1 | $3-5 | Anywhere | For programming |

**ESP32-A1S Sources:**
- AliExpress: Search "ESP32-A1S" or "ESP32 Audio Kit"
- Amazon: "ESP32 Audio Development Board"
- Local electronics suppliers

**Important:** Verify it includes:
- ES8388 audio codec
- 6 onboard buttons
- Micro USB port
- Pin headers (or ability to solder them)

---

### Power System

| Item | Specification | Quantity | Est. Price | Source | Notes |
|---|---|---|---|---|---|
| 18650 Battery Holder | 4-cell with 5V USB-A output | 1 | $8-12 | AliExpress, Amazon | Must have built-in 5V regulation |
| 18650 Li-ion Batteries | 2500-3500mAh, protected | 4 | $12-20 | Battery stores | Use quality cells only |
| USB-A to Breadboard Cable | Standard or cut cable | 1 | $2-3 | Anywhere | Connects battery to power module |
| Breadboard Power Module | Dual rail, 5V, with switch | 1 | $2-4 | AliExpress, Amazon | MB102 or similar |

**Battery Recommendations:**
- Samsung 25R (2500mAh, 20A)
- LG HG2 (3000mAh, 20A)
- Sony VTC6 (3000mAh, 15A)
- Panasonic NCR18650B (3400mAh, 6.8A)

⚠️ **Safety:** Always use protected cells from reputable brands. Avoid cheap unbranded batteries.

**18650 Holder Requirements:**
- Built-in boost converter to 5V
- USB-A output port (5V)
- Micro-USB charging port
- Protection circuitry
- Output current: 3A minimum, 5A recommended
- Wake button to activate output

---

### Electromagnet & Driver

| Item | Specification | Quantity | Est. Price | Source | Notes |
|---|---|---|---|---|---|
| MOSFET Trigger Module | AOD4184 or similar, 5V logic | 1 | $2-4 | AliExpress, Amazon | Must have flyback diode |
| Electromagnet | 5V, 1-2A, solenoid type | 1 | $5-10 | AliExpress, Amazon | 20mm-30mm diameter recommended |

**MOSFET Module Search Terms:**
- "MOSFET trigger module"
- "AOD4184 module"
- "MOSFET switch module 5V"
- "Low-side MOSFET driver"

**Required Features:**
- 3.3V/5V logic input
- Built-in flyback diode
- Status LED indicator
- 5A+ current handling

**Electromagnet Options:**

| Type | Specs | Best For | Price |
|---|---|---|---|
| Small | 5V/1A, 20mm | Desktop display | $5-7 |
| Medium | 5V/1.5A, 25mm | Standard build | $7-10 |
| Large | 5V/2A, 30mm | Maximum effect | $10-15 |

---

### LED System

| Item | Specification | Quantity | Est. Price | Source | Notes |
|---|---|---|---|---|---|
| WS2812B LED Ring | 24 LEDs, 5V | 1 | $5-10 | AliExpress, Amazon | 12 or 16 LED also works |
| Jumper Wires | Female-Female, 10cm | 5-10 | $2-3 | Electronics store | For connections |

**LED Ring Options:**

| Size | LED Count | Diameter | Best For | Price |
|---|---|---|---|---|
| Small | 12 LEDs | 37mm | Compact builds | $3-5 |
| Medium | 16 LEDs | 44mm | Standard | $4-6 |
| **Recommended** | **24 LEDs** | **66mm** | **Best effect** | **$6-10** |
| Large | 32 LEDs | 82mm | Big displays | $8-12 |

**LED Strip Alternative:**
- WS2812B strip, 5V, 60 LEDs/m
- Cut to desired length
- More flexible mounting
- $8-12 per meter

---

### Electronic Components

| Item | Specification | Quantity | Est. Price | Source | Notes |
|---|---|---|---|---|---|
| Resistor | 330Ω, 1/4W | 1 | $0.10 | Electronics store | For LED data line |
| Capacitor (optional) | 100-470µF, 16V+ | 2 | $0.50 | Electronics store | Power filtering |
| Flyback Diode (optional) | SS34, 1N5819, or UF4007 | 1 | $0.20 | Electronics store | If not on MOSFET module |

**Component Kit Option:**
- Generic resistor/capacitor kit: $5-10
- Includes all needed values plus extras

---

### Wiring & Connectors

| Item | Specification | Quantity | Est. Price | Source | Notes |
|---|---|---|---|---|---|
| Hookup Wire | 22-24 AWG, stranded | 3m | $3-5 | Electronics store | Multiple colors |
| Power Wire | 18-20 AWG, stranded | 1m | $2-3 | Electronics store | Red and black |
| Dupont Connectors | Male/Female headers | 20 | $2-3 | AliExpress, Amazon | Crimping tool helpful |
| Heat Shrink Tubing | Assorted sizes | 1 pack | $3-5 | Electronics store | For insulation |
| Breadboard (optional) | 400 or 830 tie-points | 1 | $3-6 | Electronics store | For prototyping |

**Wire Color Recommendations:**
- Red: +5V power
- Black: Ground (GND)
- Yellow/White: Signal (GPIO 22, 23)
- Other: Additional signals

---

### Ferrofluid Display

| Item | Specification | Quantity | Est. Price | Source | Notes |
|---|---|---|---|---|---|
| Ferrofluid | 10-50ml | 1 | $10-30 | Amazon, specialty | Amount depends on display size |
| Display Container | Clear, flat bottom | 1 | $5-15 | Varies | Glass vial, petri dish, custom |
| Mineral Oil (optional) | Clear, cosmetic grade | 50ml | $5-10 | Pharmacy, cosmetic | Dilutes ferrofluid |

**Ferrofluid Options:**

| Type | Amount | Use Case | Price |
|---|---|---|---|
| Educational | 10ml | Small display, testing | $10-15 |
| **Standard** | **30ml** | **Recommended** | **$20-25** |
| Large | 50ml+ | Big displays | $30-40 |

**Container Ideas:**
- Glass vial with flat bottom (chemistry supply)
- Petri dish (biology supply)
- Watch glass dish
- Custom 3D printed holder
- Small aquarium-style container

---

## Optional Components

### Enhancements

| Item | Purpose | Est. Price | Priority |
|---|---|---|---|
| Heatsink | Cooling for electromagnet | $2-4 | Low |
| Small Fan (5V) | Active cooling | $2-5 | Low |
| 3.5mm Audio Jack | AUX input port | $1-2 | Medium |
| Status LEDs | Power/status indicators | $1-2 | Low |
| Enclosure Material | 3D printed or acrylic | $5-20 | High |

### Development/Testing

| Item | Purpose | Est. Price |
|---|---|---|
| Multimeter | Testing voltage/continuity | $10-30 |
| Bench Power Supply | Stable 5V for testing | $20-50 |
| Soldering Iron | Permanent connections | $15-40 |
| Wire Stripper | Clean wire prep | $5-15 |
| Crimping Tool | Dupont connectors | $10-25 |

---

## Tools Required

### Essential

- [ ] Screwdriver set (Phillips, flat)
- [ ] Wire cutters
- [ ] Wire strippers
- [ ] Needle-nose pliers
- [ ] Multimeter (for testing)

### Helpful

- [ ] Soldering iron & solder
- [ ] Helping hands / PCB holder
- [ ] Heat gun (for heat shrink)
- [ ] Label maker
- [ ] Crimping tool (for Dupont connectors)

---

## Where to Buy

### Online Retailers

**International:**
- **AliExpress** - Cheapest, slow shipping (2-4 weeks)
- **Amazon** - Fast shipping, higher prices
- **eBay** - Varies by seller
- **Banggood** - Good electronics selection
- **Adafruit** - Quality components, US-based
- **SparkFun** - Great for learning, tutorials

**Regional:**
- **North America:** Digi-Key, Mouser, Adafruit, SparkFun
- **Europe:** RS Components, Farnell, Conrad Electronic
- **Asia:** Taobao, local electronics markets

### Local Options

- Electronics hobby stores
- Radio Shack (where available)
- University surplus stores
- Maker spaces (often have parts bins)
- Local electronics markets

---

## Cost Breakdown by Category

### Minimum Build (Basic Functionality)

| Category | Cost |
|---|---|
| ESP32-A1S | $20 |
| 4x18650 + Holder | $15 |
| MOSFET Module | $3 |
| Electromagnet | $7 |
| LED Ring (24) | $8 |
| Resistors/Wire | $5 |
| Breadboard Power | $3 |
| USB Cable | $2 |
| Ferrofluid + Container | $25 |
| **Total** | **~$88** |

### Recommended Build (Better Components)

| Category | Cost |
|---|---|
| ESP32-A1S | $25 |
| Quality 18650s + Holder | $25 |
| MOSFET Module | $4 |
| Medium Electromagnet | $10 |
| LED Ring (24) | $10 |
| Components/Wire/Connectors | $10 |
| Breadboard Power | $4 |
| USB Cable | $3 |
| Ferrofluid (30ml) | $25 |
| Container | $10 |
| **Total** | **~$126** |

### Deluxe Build (All Options)

| Category | Cost |
|---|---|
| ESP32-A1S | $25 |
| High-capacity 18650s + Holder | $30 |
| MOSFET Module | $4 |
| Large Electromagnet | $15 |
| LED Ring (32) | $12 |
| Premium Components | $15 |
| Heatsink + Fan | $7 |
| 3D Printed Enclosure | $15 |
| Quality Ferrofluid (50ml) | $35 |
| Custom Container | $15 |
| **Total** | **~$173** |

---

## Battery Charger

**Not included in main BOM but essential:**

| Item | Type | Price | Notes |
|---|---|---|---|
| Smart Charger | 4-bay, Li-ion | $15-30 | Nitecore, XTAR, etc. |
| USB Charger | 18650 compatible | $8-15 | Convenient but slower |

**Note:** Most 4x18650 holders have built-in Micro-USB charging, so external charger is optional but recommended for longevity.

**Recommended Features:**
- Individual cell monitoring
- Multiple charge rates (0.5A, 1A, 2A)
- Status display
- Auto-shutoff when full
- Compatible with protected cells

**Charger Brands:**
- Nitecore (high quality, reliable)
- XTAR (good value)
- Opus (feature-rich)
- LiitoKala (budget option)

---

## Bulk Discounts

If building multiple units or group buy:

| Item | Single | 5-Pack | 10-Pack | Savings |
|---|---|---|---|---|
| ESP32-A1S | $20 | $90 | $160 | 20% |
| LED Rings | $8 | $35 | $65 | 19% |
| MOSFET Modules | $3 | $12 | $20 | 33% |
| Electromagnets | $8 | $35 | $60 | 25% |

---

## Shopping List Template

Copy this checklist when ordering:

```
[ ] ESP32-A1S Audio Kit v2.2
[ ] 4x 18650 batteries (protected)
[ ] 4x18650 holder with USB-A output & Micro-USB charging
[ ] USB-A cable (for battery to breadboard)
[ ] Breadboard power module (with master switch)
[ ] MOSFET trigger module (with diode)
[ ] Electromagnet (5V, 1-2A)
[ ] WS2812B LED ring (24 LEDs)
[ ] 330Ω resistor (1x)
[ ] Hookup wire (22-24 AWG, 3m)
[ ] Power wire (18-20 AWG, 1m)
[ ] Dupont connectors (20+)
[ ] Heat shrink tubing
[ ] Ferrofluid (30ml)
[ ] Display container
[ ] Micro USB cable (for programming)

Optional:
[ ] Capacitors (100µF, 470µF)
[ ] 3.5mm audio jack
[ ] Heatsink for coil
[ ] 5V fan
[ ] Enclosure material
```

---

## Substitutions & Alternatives

### ESP32 Board
- ❌ ESP32 DevKit (lacks audio codec)
- ✅ ESP32-A1S v2.2 (recommended)
- ⚠️ Other ESP32-Audio-Kit versions (may need code changes)

### Batteries
- ✅ 18650 protected cells (recommended)
- ⚠️ 18650 unprotected (only if you know what you're doing)
- ⚠️ Power bank with 5V output (possible but less portable)
- ❌ AA batteries (insufficient current)

### MOSFET Module
- ✅ AOD4184 module (recommended)
- ✅ IRF520 module (if has flyback diode)
- ⚠️ Standalone MOSFET (need to add diode yourself)
- ❌ Relay module (too slow, will click)

### LEDs
- ✅ WS2812B (recommended, most common)
- ✅ SK6812 (compatible, RGBW option)
- ⚠️ APA102 (faster but needs 2 pins)
- ❌ Standard RGB LEDs (not addressable)

---

## Quality Tips

### Don't Cheap Out On:
1. **Batteries** - Safety critical, affects performance
2. **ESP32-A1S** - Clones may have issues
3. **Battery holder** - Need reliable 5V output

### OK to Economize:
1. Resistors - Generic is fine
2. Wire - Any copper stranded wire works
3. Connectors - Function over brand

### Avoid:
1. Unbranded lithium batteries
2. "Free shipping from unknown country" listings
3. Prices way below market average
4. Listings with stock photos only

---

## Inventory Checklist

Before starting assembly, verify you have:

**Electronics:**
- [ ] ESP32-A1S board with pin headers
- [ ] MOSFET module tested (LED lights up)
- [ ] LED ring responds to power (lights up)
- [ ] Electromagnet tested (gets warm when powered)

**Power:**
- [ ] Batteries charged to 4.0V+ each
- [ ] Battery holder outputs 5V at USB-A port
- [ ] Power module outputs 5V on both rails
- [ ] Breadboard master switch works

**Components:**
- [ ] 330Ω resistor measured (correct value)
- [ ] Wire properly stripped
- [ ] Connectors crimped or soldered
- [ ] Heat shrink available

**Tools:**
- [ ] Multimeter available
- [ ] Computer with Arduino IDE installed
- [ ] USB cable connects to ESP32
- [ ] Work surface cleared

---

## Version History

- **v2.0** - Updated for battery-powered design with 4x18650
- **v1.0** - Original USB-C PD version

---

## Need Help?

**Can't find a part?**
- Ask in GitHub Discussions
- Check MakerWorld project page
- Post in Issues with your location

**Part recommendations needed?**
- Specify your country/region
- Mention budget constraints
- List what you've already found

---

**Project**: [FerroWave](https://github.com/matoslav/FerroWave)  
**Author**: Makarov87  
**Crowdfunded by**: [MakerWorld Community](https://makerworld.com/en/crowdfunding/70-ferrowave)  
**License**: MIT

*Thank you to all MakerWorld backers who made this project possible!* 🙏

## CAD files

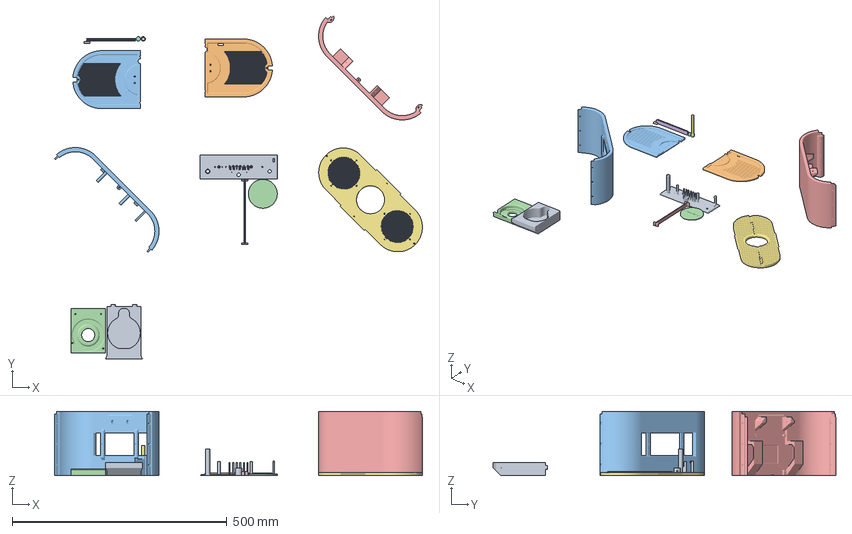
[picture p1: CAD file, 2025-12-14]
3D print files/print profiles/P1S-06-FerroWave.3mf
857.2 x 798.9 x 150.0 mm
FerroWave holder
Back panel right
Back panel left
LED & Magnet holder
Bottom Panel
Front left bar
Front Face
Front right bar
Control Panel
Battery Wake Button
Top Panel
Back Circle
Left bar
Right bar
Power switch_A
Power switch_B

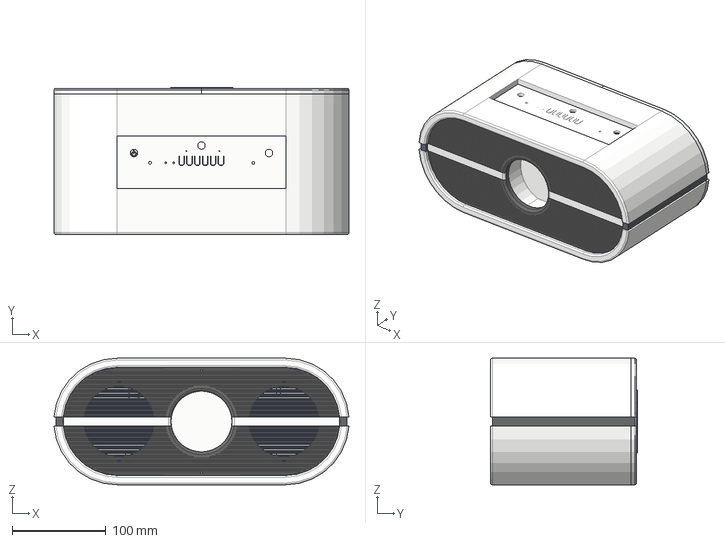
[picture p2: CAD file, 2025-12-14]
3D print files/Step/FerroWave.step
314.6 x 157.0 x 135.0 mm

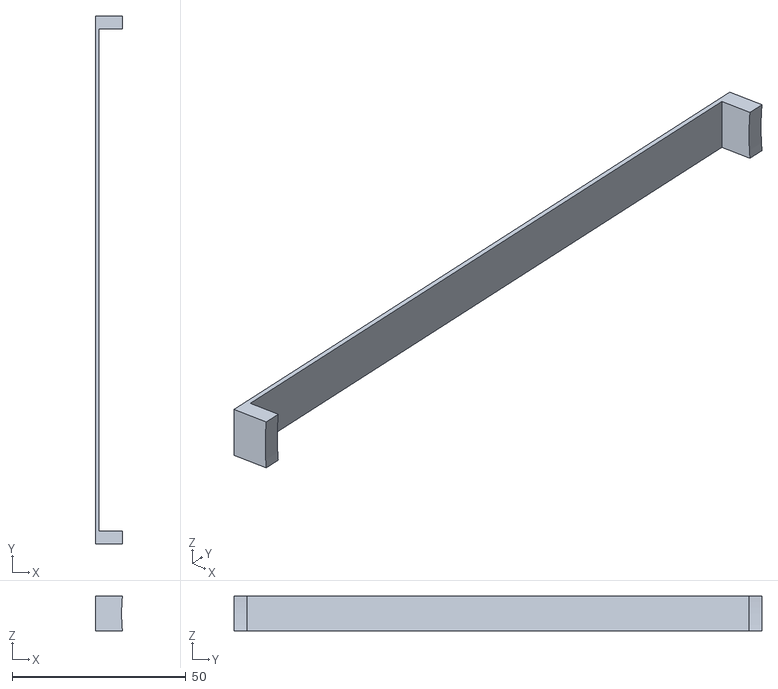
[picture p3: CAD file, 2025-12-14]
3D print files/Stl/Left bar.stl
7.72 x 152.0 x 10.0

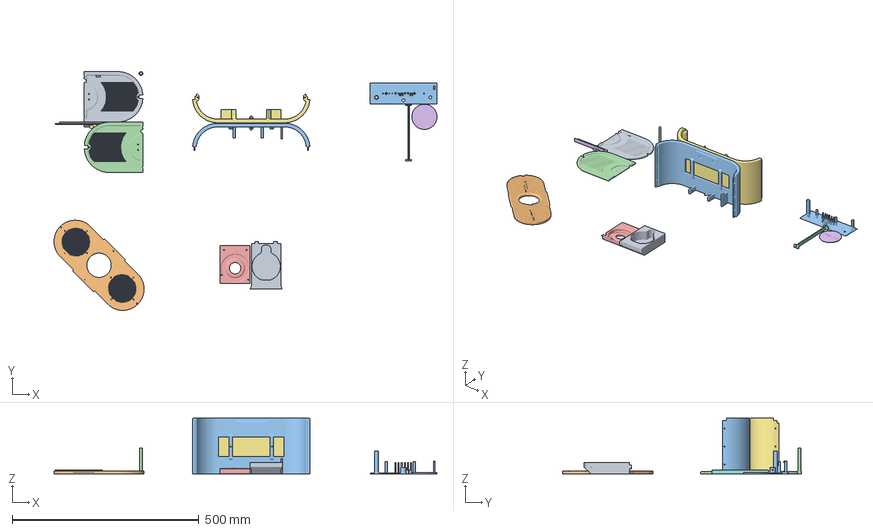
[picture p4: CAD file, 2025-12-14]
3D print files/print profiles/H2C-04-FerroWave.3mf
1026.8 x 640.1 x 150.0 mm
FerroWave holder
Front Face
Control Panel
Power switch_A
LED & Magnet holder
Back Circle
Bottom Panel
Left bar
Back panel right
Right bar
Top Panel
Back panel left
Front left bar
Front right bar
Power switch_B
Battery Wake Button

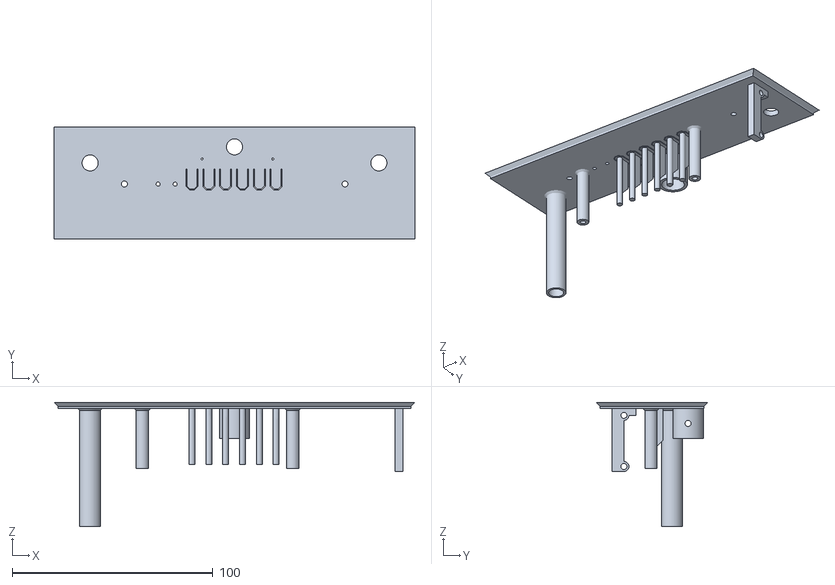
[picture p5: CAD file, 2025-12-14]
3D print files/Stl/Control Panel.stl
180.0 x 56.0 x 62.0

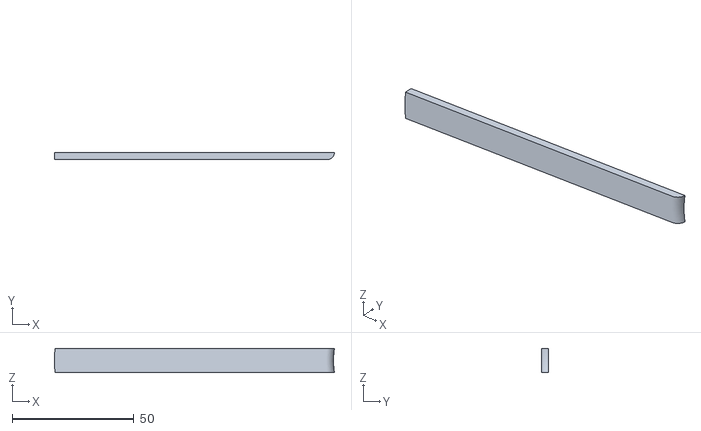
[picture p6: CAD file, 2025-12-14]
3D print files/Stl/Front left bar.stl
115.1 x 3.00 x 10.0

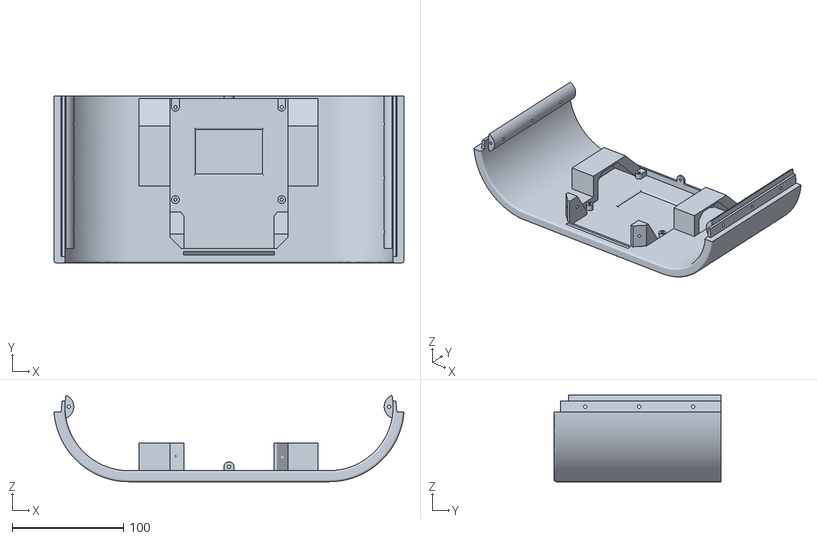
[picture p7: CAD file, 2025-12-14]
3D print files/Stl/Bottom Panel.stl
314.6 x 150.0 x 77.8

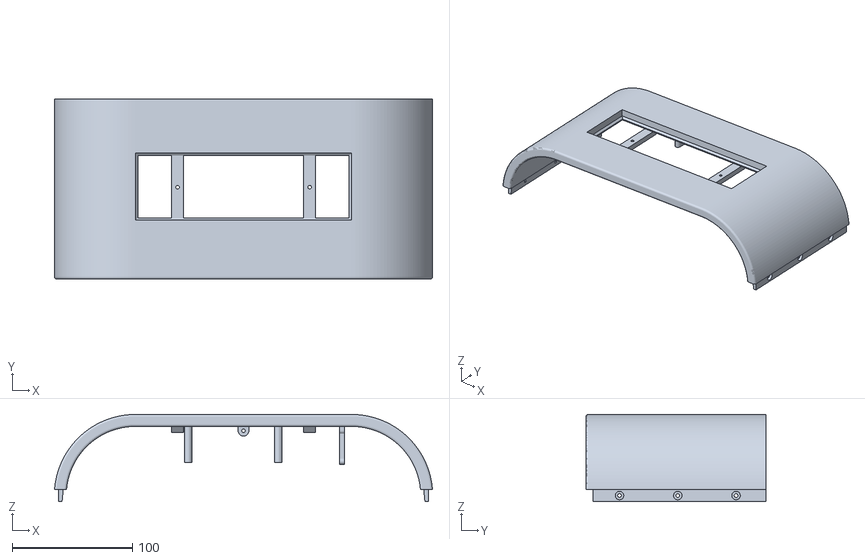
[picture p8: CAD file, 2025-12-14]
3D print files/Stl/Top Panel.stl
314.6 x 150.0 x 72.5

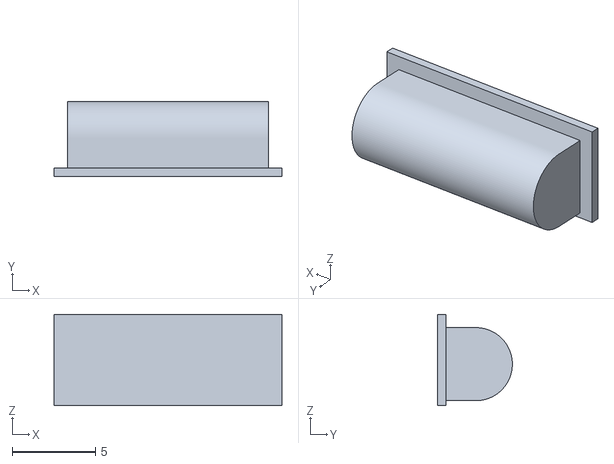
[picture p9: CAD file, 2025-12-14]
3D print files/Stl/Battery Wake Button.stl
13.7 x 4.50 x 5.50

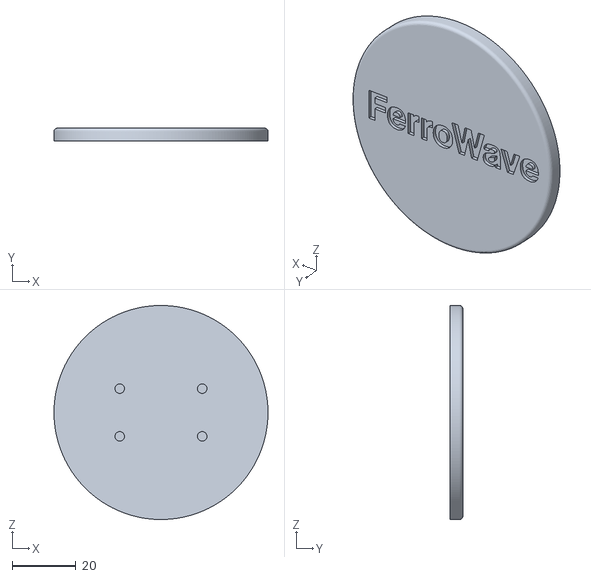
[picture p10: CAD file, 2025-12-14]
3D print files/Stl/Back Circle.stl
67.4 x 4.00 x 67.4

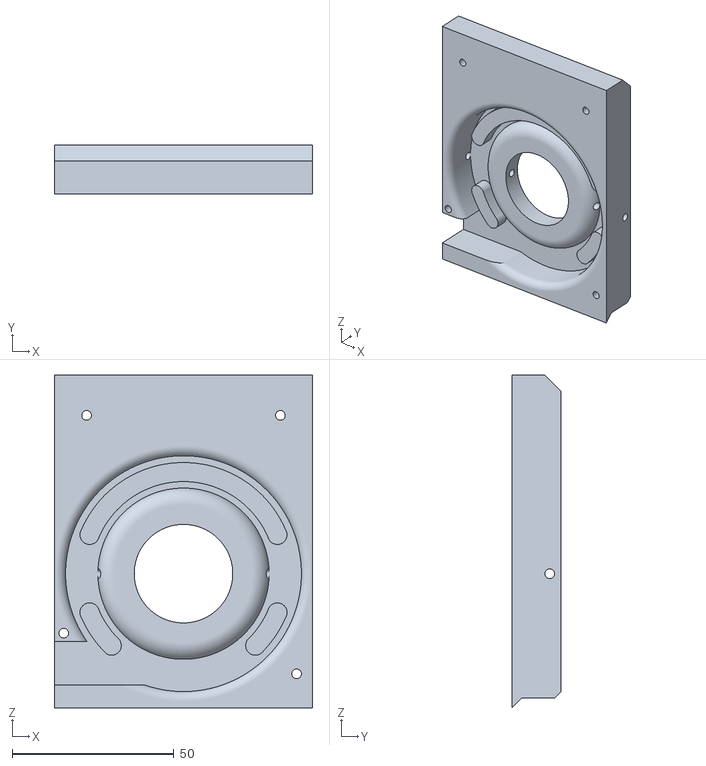
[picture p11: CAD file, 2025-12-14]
3D print files/Stl/LED & Magnet holder.stl
80.0 x 15.2 x 103.1

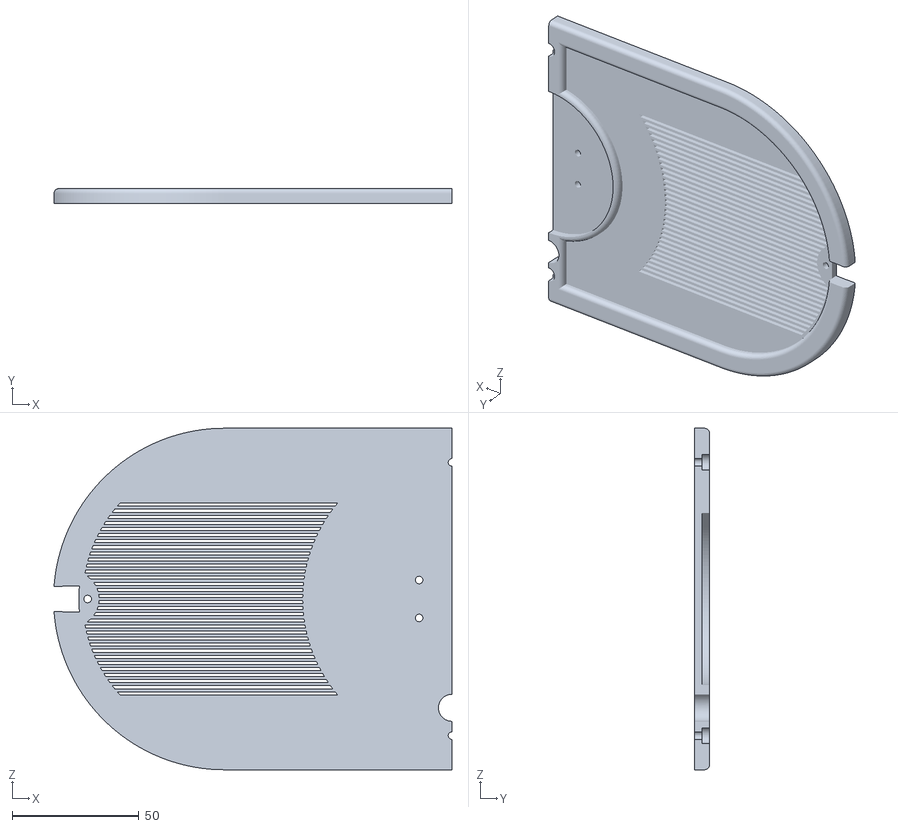
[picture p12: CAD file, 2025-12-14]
3D print files/Stl/Back panel left.stl
157.3 x 6.00 x 135.0

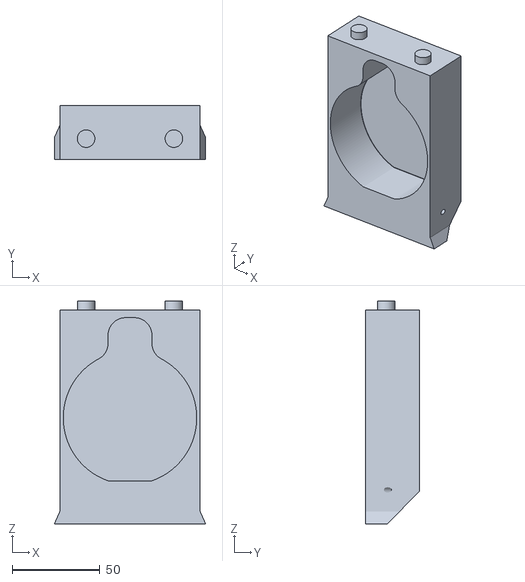
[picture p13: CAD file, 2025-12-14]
3D print files/Stl/FerroWave holder.stl
86.2 x 31.0 x 127.0

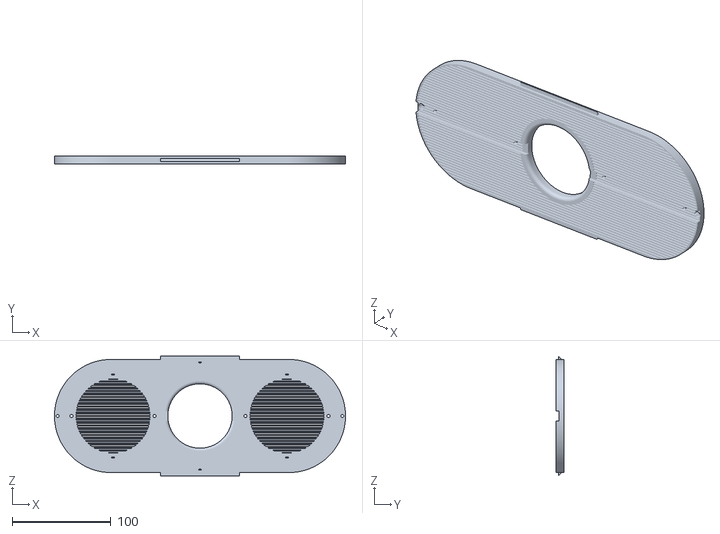
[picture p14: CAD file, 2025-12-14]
3D print files/Stl/Front Face.stl
294.4 x 8.00 x 121.0

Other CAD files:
3D print files/print profiles/H2C-06-FerroWave.3mf
3D print files/print profiles/P1S-04-FerroWave.3mf
3D print files/Stl/Right bar.stl
3D print files/Stl/Back panel right.stl
3D print files/3mf/FerroWave.3mf
3D print files/Stl/FerroWave.stl
3D print files/Stl/Front right bar.stl
3D print files/Stl/Power switch.stl

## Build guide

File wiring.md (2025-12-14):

# FerroWave Wiring Guide

Complete wiring instructions for the FerroWave ferrofluid visualizer.

---

## Table of Contents

- [Safety Warning](#safety-warning)
- [Required Components](#required-components)
- [Power Distribution](#power-distribution)
- [ESP32-A1S Connections](#esp32-a1s-connections)
- [Electromagnet Circuit](#electromagnet-circuit)
- [LED Ring Wiring](#led-ring-wiring)
- [Battery Power System](#battery-power-system)
- [Wiring Diagram](#wiring-diagram)
- [Step-by-Step Assembly](#step-by-step-assembly)
- [Testing](#testing)
- [Troubleshooting](#troubleshooting)

---

## Safety Warning

⚠️ **IMPORTANT SAFETY INFORMATION**

- Always disconnect power before making wiring changes
- Double-check polarity before connecting power
- Electromagnets can get HOT - monitor temperature during operation
- Use proper gauge wire for current requirements
- Include a flyback diode to protect the MOSFET
- Never exceed the voltage/current ratings of components
- **Battery Safety**: Never short circuit 18650 cells
- Use proper 18650 batteries with protection circuits
- Charge batteries with appropriate charger only
- Monitor battery temperature during use
- Work in a well-ventilated area
- Keep ferrofluid away from electronics and clothing (it stains!)

---

## Required Components

### Main Components

| Component | Specification | Notes |
|---|---|---|
| ESP32-A1S Audio Kit v2.2 | With ES8388 codec | Must be v2.2 or compatible |
| MOSFET Trigger Module | AOD4184 or similar | Low-side N-channel with flyback diode |
| Electromagnet | 5V, 1-2A | Sized for 5V operation |
| WS2812B LED Ring | 24 LEDs (or similar) | 5V addressable RGB |
| 4x18650 Battery Holder | 5V output module | With built-in 5V regulation |
| Breadboard Power Module | Dual rail | Creates 5V power rails |

### Additional Components

| Component | Specification | Purpose |
|---|---|---|
| Flyback Diode | SS34, 1N5819, or UF4007 | Coil protection (if not on module) |
| LED Data Resistor | 330Ω | Protects WS2812B data line |
| Wire | 22-24 AWG | For signal connections |
| Power Wire | 18-20 AWG | For power distribution |
| Heat Shrink Tubing | Various sizes | Insulate connections |
| Dupont Connectors | Male/Female | Easy connections |
| Breadboard (optional) | Full or half size | For prototyping |

### Battery System

| Component | Specifications | Notes |
|---|---|---|
| 18650 Batteries | 4x cells, 2500-3500mAh | Use protected cells |
| 4x18650 Holder | With 5V USB-A output | Built-in boost converter |
| USB-A to Breadboard Cable | Standard USB cable | Connects battery to power module |

---

## Power Distribution

### Single 5V Rail System

The 4x18650 battery pack provides a clean 5V rail for all components:

```
4x18650 Battery Pack (5V Output)
         |
         v
    Power Switch
         |
         v
  Breadboard Power Module
    (+ and - rails)
         |
         ├──> ESP32-A1S (5V + GND)
         ├──> LED Ring (5V + GND)
         └──> Electromagnet + (5V)
              Electromagnet - via MOSFET
```

### Power Distribution Details

**Advantages of this setup:**
- ✅ Single voltage rail - simple and clean
- ✅ Portable with battery power
- ✅ No voltage converters needed
- ✅ Breadboard rails make connections easy
- ✅ Lower power consumption (5V coil)

**Current Draw Estimates:**
- ESP32-A1S: ~300-500mA
- LED Ring (24 LEDs): 500mA-1.4A (depends on brightness)
- Electromagnet: 1-2A (depends on duty cycle)
- **Total**: 2-4A typical, up to 5A peak

**Battery Life Calculation:**
- 4x 3000mAh cells = ~3000mAh at 5V
- At 2A average: ~1.5 hours runtime
- At 3A average: ~1 hour runtime

---

## ESP32-A1S Connections

### Pin Assignments

| Pin | Function | Connection |
|-----|---|---|
| GPIO 22 | PWM Output | MOSFET Gate |
| GPIO 23 | LED Data | WS2812B DIN (through 330Ω) |
| GPIO 36 | Button 1 | Magnet Mode ↑ (Built-in) |
| GPIO 39 | Button 2 | Magnet Mode ↓ (Built-in) |
| GPIO 34 | Button 3 | LED Mode ↑ (Built-in) |
| GPIO 35 | Button 4 | LED Mode ↓ (Built-in) |
| GPIO 32 | Button 5 | EQ Preset ↑ (Built-in) |
| GPIO 33 | Button 6 | EQ Preset ↓ (Built-in) |
| 5V | Power In | From breadboard + rail |
| GND | Ground | From breadboard - rail |

### I2S Audio (Pre-wired on board)

| Pin | Function |
|-----|---|
| GPIO 27 | I²S BCK (Bit Clock) |
| GPIO 25 | I²S WS (Word Select) |
| GPIO 26 | I²S DATA OUT |
| GPIO 35 | I²S DATA IN (AUX) |
| GPIO 0 | I²S MCLK |

### Power Connection

```
Breadboard (+) Rail  ──> ESP32-A1S 5V Pin
Breadboard (-) Rail  ──> ESP32-A1S GND Pin
```

---

## Electromagnet Circuit

### Complete Electromagnet Wiring

```
           Breadboard (+) Rail (5V)
                     │
                     ├─────────────┐
                     │             │
                 [Flyback Diode]   │
                     │        [Electromagnet]
                     │             │
                     └─────────────┤
                                   │
                              Drain (D)
                                   │
                           [MOSFET Trigger]
                                   │
                              Source (S)
                                   │
                         Breadboard (-) Rail
                                  
ESP32 GPIO 22 ──────────> Gate (G)
```

### Component Details

**MOSFET Trigger Module:**
- **Input**: 3.3V logic from GPIO 22
- **Output**: Switches coil ground (up to 5A)
- **Built-in**: Flyback diode, status LED
- **Recommended**: AOD4184 module or similar
- **Voltage**: 5V coil operation

**Flyback Diode (if external):**
- **Cathode (stripe)** → Coil + (breadboard +5V rail)
- **Anode** → Coil - (MOSFET drain)
- **Purpose**: Protects MOSFET from voltage spikes
- **Required**: Yes, if not built into MOSFET module

**Gate Connection:**
- Connect GPIO 22 directly to MOSFET gate (no resistor needed)
- Some designs use 100Ω resistor, but not required for this build

### MOSFET Module Connection

```
ESP32-A1S                    MOSFET Trigger Module
─────────                    ──────────────────────
GPIO 22  ──────────────────>  Signal In (S/SIG)
GND      ──────────────────>  GND

Breadboard (+) Rail ──────>  V+ or VCC
Breadboard (-) Rail ──────>  GND

MOSFET Trigger Module        Electromagnet
──────────────────────       ─────────────
OUT+ / DRAIN ─────────────>  Coil (-)

Breadboard (+) Rail ──────>  Coil (+)
```

**Status LED on module:**
- Most MOSFET trigger modules have a built-in LED
- LED lights when coil is energized
- Useful for debugging

---

## LED Ring Wiring

### WS2812B Connection

```
Breadboard (+) Rail ─────────> LED Ring VCC/5V
Breadboard (-) Rail ─────────> LED Ring GND
ESP32 GPIO 23 ─[330Ω]──────> LED Ring DIN
```

### Important Notes

**Data Line Resistor:**
- **Required**: 330Ω resistor between GPIO 23 and DIN
- **Purpose**: Level shifting protection, signal integrity
- **Position**: Close to ESP32 output

**Power Considerations:**
- 24 LEDs at full white = ~1.4A
- Keep LED brightness moderate to extend battery life
- Default brightness (100/255) draws ~500mA

**Wiring Tips:**
- Keep data line short (< 12 inches if possible)
- Twist data and ground wires together
- Use same ground reference as ESP32

### LED Ring Pinout

Standard WS2812B rings have 3 connections:

| Pin | Name | Connection |
|-----|---|---|
| 1 | VCC/5V | Breadboard + rail |
| 2 | GND | Breadboard - rail |
| 3 | DIN | GPIO 23 through 330Ω resistor |

Some rings also have:
- **DOUT**: Data out (for chaining, not used)

---

## Battery Power System

### 4x18650 Battery Pack Setup

```
[18650][18650][18650][18650]  ←─ 4 cells in holder
         |
    [5V Boost Module]           ←─ Built into holder
         |
    [USB-A Output Port]         ←─ 5V output
         |
    [USB Cable]                 ←─ USB-A to breadboard
         |
         v
  [Breadboard Power Module]
    (with master switch)
         |
         +────────> (+) Rails
         |
         └────────> (-) Rails
```

**Charging:**
- Micro-USB charging port on battery pack
- Use 5V USB charger (1A-2A recommended)
- Charge indicator LED on pack

**Wake/Power:**
- Button on battery pack: Wake-up only (activates USB output)
- Master power switch: On breadboard power module
- Press battery wake button, then turn on breadboard switch

### Battery Pack Features

**Typical 4x18650 5V modules include:**
- ✅ Built-in voltage regulation to 5V
- ✅ USB-A output port (5V)
- ✅ Micro-USB charging port (5V input)
- ✅ Protection circuits
- ✅ LED charging/power indicator
- ✅ Wake-up button to activate output
- ✅ 2A-5A output capability

### Power Module Connection

```
4x18650 Pack                Breadboard Power Module
────────────                ───────────────────────
USB-A Output  ──[USB Cable]──> USB Input or VIN/GND
                               (via cut USB cable)

                       Master Switch: ON
                               |
                       (+) Rails distribute to:
                       ├─> ESP32-A1S
                       ├─> LED Ring  
                       └─> Electromagnet

                       (-) Rails (common ground) to:
                       ├─> ESP32-A1S
                       ├─> LED Ring
                       └─> MOSFET Source
```

**Note:** If breadboard power module has USB input, use standard USB-A to Micro-USB cable. Otherwise, cut USB cable and connect red wire to VIN, black to GND.

### Breadboard Power Module

Most breadboard power modules have:
- Dual voltage inputs (we only use one at 5V)
- Two sets of (+) and (-) rails
- **Master power switch** (main on/off control)
- Status LEDs
- Optional USB input port

**Connection:**
```
Battery Pack USB-A ──[USB Cable]──> Power Module USB/VIN Input

Power Module Master Switch: Controls entire system

Power Module creates two rails:
  Rail 1: (+) and (-) 
  Rail 2: (+) and (-) (paralleled)
```

### Power Switch

**System Power Control:**
1. **Battery Wake Button**: Press to activate USB-A output on battery pack
2. **Breadboard Master Switch**: Main on/off for entire FerroWave system

**Power-On Sequence:**
1. Press battery pack wake button (activates 5V output)
2. Turn on breadboard power module master switch
3. System powers on

**Power-Off Sequence:**
1. Turn off breadboard power module master switch
2. Battery pack will auto-sleep after period of inactivity

---

## Wiring Diagram

### Complete System Overview

```
┌──────────────────────────────────────────────────────┐
│         4x18650 Battery Pack (5V USB-A Out)          │
│         Micro-USB In (charging) | Wake Button        │
└────────────┬─────────────────────────────────────────┘
             │
        [USB Cable]
             │
             v
    ┌────────────────────┐
    │  Breadboard Power  │
    │      Module        │
    │  [Master Switch]   │
    └────────────────────┘
         (+)    (-)
          │      │
    ──────┴──────┴──────
    │      │      │
    │      │      └────────────────┤
    │      │                       │
    │      │                       │
    v      v                       v
┌────────────────┐            ┌────────┐
│  ESP32-A1S     │            │ MOSFET │
│  ┌──────────┐  │            │ Module │
│  │ GPIO 22  ├──┼────────────>  Gate  │
│  │ GPIO 23  ├──┼─[330Ω]─┐   └────────┘
│  │          │  │         │       │
│  │   5V     │<─┘         │     Drain
│  │   GND    │<───────────┤       │
│  └──────────┘            │       v
└────────────────┘          │  [Electromagnet]
                            │       │
                            │       v
                        ┌───────────────┐
                        │  LED Ring     │
                        │  (24 LEDs)    │
                        │               │
                        │  DIN  VCC GND │
                        └───┬───┬───┬───┘
                            │   │   │
                            │   │   └───> (-) Rail
                            │   └───────> (+) Rail
                            └───────────> GPIO 23
```

---

## Step-by-Step Assembly

### Step 1: Prepare Battery Pack

1. Insert 4x 18650 batteries (observe polarity!)
2. Press wake button to activate output
3. Verify 5V output at USB-A port with multimeter (if desired)
4. Connect USB cable from battery to breadboard power module

### Step 2: Setup Breadboard Power

1. Connect USB cable from battery pack to breadboard power module
   - If module has USB input, use standard cable
   - Otherwise cut cable and connect red→VIN, black→GND
2. Turn on breadboard master switch
3. Verify 5V on both (+) rails with multimeter
4. Verify ground continuity on both (-) rails

### Step 3: Connect ESP32-A1S

1. Connect ESP32 5V pin to breadboard (+) rail
2. Connect ESP32 GND pin to breadboard (-) rail
3. Power on and verify ESP32 LED lights up
4. If programming, connect USB cable now

### Step 4: Wire MOSFET Module

1. Connect MOSFET module VCC to breadboard (+) rail
2. Connect MOSFET module GND to breadboard (-) rail
3. Connect GPIO 22 directly to MOSFET gate (no resistor)
4. Verify gate voltage is LOW when ESP32 is off

### Step 5: Connect Electromagnet

1. Connect electromagnet (+) to breadboard (+) rail
2. Connect electromagnet (-) to MOSFET DRAIN
3. Connect MOSFET SOURCE to breadboard (-) rail
4. Double-check flyback diode orientation (if external):
   - Cathode (stripe) to (+) rail
   - Anode to coil (-)

### Step 6: Wire LED Ring

1. Solder 330Ω resistor to a wire
2. Connect resistor to GPIO 23
3. Connect other end of resistor to LED DIN
4. Connect LED VCC to breadboard (+) rail
5. Connect LED GND to breadboard (-) rail

### Step 7: Final Checks

1. ✅ All (+) connections go to breadboard (+) rail
2. ✅ All (-) connections go to breadboard (-) rail  
3. ✅ No exposed wire that could short
4. ✅ All connections are secure
5. ✅ Flyback diode is correct orientation (if external)
6. ✅ 330Ω resistor is in LED data line
7. ✅ GPIO 22 connects directly to MOSFET gate
8. ✅ USB cable from battery to breadboard is secure
9. ✅ Breadboard master switch is accessible

---

## Testing

### Pre-Power Test

**Before connecting battery:**

1. Visual inspection of all connections
2. Check for shorts with multimeter:
   - (+) rail to (-) rail should be open (> 1MΩ)
3. Verify no loose wires
4. Check polarity of all components

### Initial Power-On

1. Press battery pack wake button
2. Turn on breadboard master switch
3. **Expected behavior:**
   - ESP32 LED lights up
   - LED ring shows brief startup animation
   - No smoke, strange smells, or heat
4. If anything unexpected, turn off master switch immediately

### Functional Testing

**LED Test:**
1. LED ring should do startup animation
2. Type `c1` in Serial Monitor
3. Rainbow effect should appear
4. Try different modes (c2, c3, etc.)

**Electromagnet Test:**
1. Type `t` in Serial Monitor
2. Should hear/feel magnet activate for 2 seconds
3. MOSFET module LED should light up
4. Check coil for excessive heat

**Audio Test:**
1. Pair via Bluetooth
2. Play music
3. LEDs should react to audio
4. Ferrofluid should move with music

---

## Troubleshooting

### Power Issues

**ESP32 won't power on:**
- Check battery charge level
- Verify power switch is on
- Check breadboard power module connections
- Measure voltage at (+) rail (should be ~5V)

**System resets randomly:**
- Battery may be depleted
- Current draw too high (reduce LED brightness)
- Poor connections causing voltage drops

### Electromagnet Issues

**Coil doesn't activate:**
- Check MOSFET module power (VCC and GND)
- Verify GPIO 22 connection to gate
- Test with `t` command
- Check MOSFET module LED indicator

**Coil gets very hot:**
- Reduce max duty: `d70`
- Reduce sensitivity: `s80`
- Add heatsink to coil
- Improve airflow

### LED Issues

**LEDs don't light:**
- Check LED VCC connection to (+) rail
- Check LED GND connection to (-) rail
- Verify 330Ω resistor in data line
- Try `l255` for maximum brightness

**LEDs flicker or glitch:**
- Check ground connection (must be shared with ESP32)
- Verify 330Ω resistor is present
- Try shorter wires to LED DIN

---

**Project**: [FerroWave](https://github.com/matoslav/FerroWave)  
**Author**: Makarov87  
**Crowdfunded by**: MakerWorld Community

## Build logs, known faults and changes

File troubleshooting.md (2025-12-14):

# FerroWave Troubleshooting Guide

Complete troubleshooting guide for resolving common issues with FerroWave.

---

## Quick Diagnostic Checklist

Before diving into specific issues, run through this quick checklist:

- [ ] Battery pack wake button pressed
- [ ] Breadboard master switch is ON
- [ ] Batteries are charged (check voltage)
- [ ] All connections are secure
- [ ] No visible shorts or damaged wires
- [ ] Serial Monitor shows output at 115200 baud
- [ ] Arduino IDE shows successful upload
- [ ] All three libraries are installed

---

## Table of Contents

- [Power Issues](#power-issues)
- [Compilation Errors](#compilation-errors)
- [Upload Issues](#upload-issues)
- [Audio Problems](#audio-problems)
- [Electromagnet Issues](#electromagnet-issues)
- [LED Problems](#led-problems)
- [Button Issues](#button-issues)
- [Performance Issues](#performance-issues)
- [Battery Problems](#battery-problems)

---

## Power Issues

### System Won't Power On

**Symptoms:**
- No LEDs light up
- ESP32 is completely dead
- No Serial Monitor output

**Solutions:**

1. **Check Battery Charge**
   ```
   - Press battery wake button
   - Check battery indicator LEDs
   - Charge if needed (via Micro-USB port)
   - Try with fresh batteries
   ```

2. **Verify Breadboard Master Switch**
   ```
   - Is switch in ON position?
   - Check power LED on breadboard module
   - Try toggling switch off/on
   ```

3. **Check USB Cable Connection**
   ```
   - Verify USB cable from battery to breadboard
   - Try different USB cable
   - Check for loose connections
   ```

4. **Check Breadboard Power Module**
   ```
   - Measure voltage at (+) rail (should be 5V)
   - Verify input connections
   - Check module LEDs
   ```

---

### Random Resets or Brownouts

**Symptoms:**
- ESP32 restarts unexpectedly
- LEDs dim when coil activates
- Serial Monitor shows boot messages repeatedly

**Solutions:**

1. **Insufficient Current**
   ```
   Problem: Total current draw exceeds battery capacity
   
   Fix:
   - Reduce LED brightness: l80
   - Lower max duty: d70
   - Use less aggressive magnet mode
   - Check battery capacity (use higher capacity cells)
   ```

2. **Poor Connections**
   ```
   Problem: Loose wires cause voltage drops
   
   Fix:
   - Check USB cable connection
   - Verify breadboard power connections
   - Ensure all wires are secure
   - Check for oxidized contacts
   ```

3. **Battery Depletion**
   ```
   Problem: Batteries running low
   
   Fix:
   - Charge batteries via Micro-USB
   - Monitor battery indicator
   - Replace with fresh batteries
   ```

---

### Voltage Too Low/High

**Symptoms:**
- Measured voltage at ESP32 is not 5V
- Components behave erratically

**Solutions:**

**If voltage is low (<4.5V):**
- Battery is depleted - charge or replace
- Power module failing - test or replace
- Too much current draw - reduce load
- USB cable resistance - use shorter/thicker cable

**If voltage is high (>5.5V):**
- Power module misconfigured - check settings
- Replace power module (may be faulty)
- Don't exceed 5.5V - may damage ESP32

---

## Compilation Errors

### "AudioSource is ambiguous"

**Error Message:**
```
error: reference to 'AudioSource' is ambiguous
```

**Solution:**
This is fixed in the latest firmware. Update to the current version from GitHub.

---

### "Library not found"

**Error Messages:**
```
fatal error: AudioTools.h: No such file or directory
fatal error: BluetoothA2DPSink.h: No such file or directory  
fatal error: Adafruit_NeoPixel.h: No such file or directory
```

**Solutions:**

1. **Install Missing Libraries**
   ```
   Arduino IDE → Sketch → Include Library → Manage Libraries
   
   Search and install:
   - "AudioTools" by pschatzmann
   - "ESP32-A2DP" by pschatzmann  
   - "Adafruit NeoPixel" by Adafruit
   ```

2. **Restart Arduino IDE** after installing libraries

---

### "Board not found" or ESP32 Missing

**Error:**
```
Error: Board esp32:esp32:esp32 not found
```

**Solutions:**

1. **Install ESP32 Board Support**
   ```
   File → Preferences → Additional Board URLs:
   https://espressif.github.io/arduino-esp32/package_esp32_index.json
   
   Tools → Board → Boards Manager
   Search: "ESP32"
   Install: "esp32 by Espressif Systems"
   ```

2. **Select Correct Board**
   ```
   Tools → Board → ESP32 Arduino → ESP32 Dev Module
   ```

---

## Upload Issues

### Can't Find COM Port

**Problem:** ESP32 doesn't appear in COM port list

**Solutions:**

1. **Install USB Drivers**
   - ESP32-A1S uses CH340 or CP2102 USB chip
   - Download drivers from manufacturer
   - Restart computer after install

2. **Try Different USB Cable**
   - Some cables are charge-only
   - Use a data-capable cable

---

### Upload Fails / Timeout

**Error:**
```
Failed to connect to ESP32
A fatal error occurred: Timed out waiting for packet header
```

**Solutions:**

1. **Hold BOOT Button**
   ```
   - Press and hold BOOT button
   - Click Upload
   - Keep holding until "Connecting..." appears
   - Release button
   ```

2. **Check Upload Settings**
   ```
   Tools → Upload Speed → Try "115200"
   Tools → Flash Frequency → "80MHz"
   ```

---

## Audio Problems

### No Bluetooth Connection

**Symptoms:**
- Device doesn't appear in Bluetooth list
- Can't pair with phone/computer

**Solutions:**

1. **Verify Bluetooth Started**
   ```
   Check Serial Monitor for:
   "Bluetooth active" or "FerroWave_AUX"
   ```

2. **Restart ESP32**
   ```
   - Power cycle device
   - Wait for Bluetooth initialization
   - Check Serial output
   ```

3. **Forget and Re-pair**
   ```
   - Remove device from Bluetooth settings
   - Restart phone/computer
   - Search for devices again
   ```

---

### Audio Stuttering or Crackling

**Symptoms:**
- Music playback has gaps
- Audio glitches frequently
- Choppy sound

**Solutions:**

1. **Power Issues**
   ```
   - Check battery charge level
   - Reduce LED brightness
   - Lower magnet duty cycle
   ```

2. **Ensure Latest Firmware**
   ```
   - Update to latest non-blocking version
   - Old versions had delay() issues
   ```

---

### AUX Input Not Working

**Symptoms:**
- No audio when AUX cable plugged in
- Auto-switch doesn't work

**Solutions:**

1. **Manual Switch**
   ```
   Serial Monitor command: aux
   This forces AUX input mode
   ```

2. **Verify Cable**
   ```
   - Use different 3.5mm cable
   - Check cable has 3 conductors (TRS)
   - Test cable with other device
   ```

---

## Electromagnet Issues

### Coil Doesn't Activate

**Symptoms:**
- No magnetic field
- Ferrofluid doesn't move
- Test pulse `t` does nothing

**Solutions:**

1. **Check MOSFET Module**
   ```
   - Verify power (VCC and GND connected)
   - Check module LED (should light when active)
   - Measure voltage at gate pin
   - Try different MOSFET module
   ```

2. **Test GPIO 22**
   ```
   Serial Monitor: type 't' for test pulse
   
   Expected:
   - MOSFET LED lights up
   - Coil gets warm
   - 2 second pulse
   ```

3. **Verify Coil**
   ```
   - Measure coil resistance (should be 2-10Ω typically)
   - Check coil connections
   - Test coil directly with 5V (briefly!)
   ```

4. **Check Wiring**
   ```
   Coil (+) → Breadboard (+) rail (5V)
   Coil (-) → MOSFET DRAIN
   MOSFET SOURCE → Breadboard (-) rail (GND)
   GPIO 22 → MOSFET GATE (direct connection)
   ```

---

### Coil Always On

**Symptoms:**
- Magnet never turns off
- Coil gets very hot
- Can't control via software

**Solutions:**

1. **Check for Short**
   ```
   - Power OFF
   - Disconnect gate wire from GPIO 22
   - If coil still on, MOSFET is shorted
   - Replace MOSFET module
   ```

2. **GPIO Stuck High**
   ```
   - Measure voltage at GPIO 22 (should be ~0V when idle)
   - If stuck high, ESP32 issue
   - Try different GPIO pin
   ```

---

### Weak Magnetic Field

**Symptoms:**
- Ferrofluid barely moves
- Expected more dramatic effect

**Solutions:**

1. **Increase Power**
   ```
   Serial commands:
   d90  (increase max duty to 90%)
   s150 (increase sensitivity to 150%)
   ```

2. **Try Different Mode**
   ```
   Try aggressive modes:
   2 (SPIKE)
   4 (CHAOS)
   ```

3. **Check Voltage**
   ```
   - Measure voltage at coil when active
   - Should be close to 5V
   - If much lower, voltage drop issue
   ```

---

### Coil Overheating

**Symptoms:**
- Coil gets very hot to touch
- Plastic melting smell
- System shuts down

**Solutions:**

1. **Reduce Duty Cycle**
   ```
   Serial commands:
   d60  (lower max duty)
   b5   (lower base duty)
   ```

2. **Use Higher Frequency**
   ```
   Serial command:
   f100  (higher frequency = less heating)
   ```

3. **Add Cooling**
   ```
   - Mount heatsink to coil
   - Add small fan
   - Improve airflow around coil
   ```

---

## LED Problems

### LEDs Don't Light Up

**Symptoms:**
- Ring stays dark
- No startup animation
- All modes show nothing

**Solutions:**

1. **Check Power**
   ```
   - Verify LED VCC connected to (+) rail (5V)
   - Verify LED GND connected to (-) rail
   - Measure voltage at LED strip (should be 5V)
   ```

2. **Check Data Connection**
   ```
   - GPIO 23 → 330Ω resistor → LED DIN
   - Verify resistor is present
   - Check for broken wire
   ```

3. **Increase Brightness**
   ```
   Serial command: l255
   Sets maximum brightness
   ```

4. **Try Different Mode**
   ```
   Serial commands:
   c1  (rainbow - easiest to see)
   c3  (solid blue pulse)
   ```

---

### Wrong Colors or Glitching

**Symptoms:**
- Colors are incorrect
- Random flickering
- Some LEDs wrong color

**Solutions:**

1. **Check Ground**
   ```
   CRITICAL: LED GND must share ground with ESP32
   
   - Verify common ground connection
   - Use breadboard (-) rail for all grounds
   - Check continuity
   ```

2. **Data Line Issues**
   ```
   - Check 330Ω resistor is present
   - Keep data wire short (< 12 inches)
   - Route away from power wires
   ```

3. **Power Insufficient**
   ```
   - Reduce LED brightness: l100
   - LEDs draw a lot of current at full white
   ```

---

## Button Issues

### Buttons Don't Respond

**Symptoms:**
- Pressing buttons does nothing
- No Serial output when pressed

**Solutions:**

1. **Check Firmware**
   ```
   - Ensure using latest firmware with button support
   - Verify button code is present
   - Check Serial output for button messages
   ```

2. **Verify Button Pins**
   ```
   ESP32-A1S button pins:
   GPIO 36, 39, 34, 35, 32, 33
   
   - These are built into the board
   - Check pin mappings in code
   ```

---

## Performance Issues

### Laggy Response

**Symptoms:**
- Delay between audio and visual response
- Sluggish magnet/LED updates

**Solutions:**

1. **Ensure Latest Firmware**
   ```
   - Old versions had blocking delays
   - Update to non-blocking version
   ```

2. **Reduce Serial Output**
   ```
   - Lots of Serial.print() slows system
   - Comment out debug messages
   ```

---

## Battery Problems

### Battery Drains Quickly

**Symptoms:**
- Only runs for 20-30 minutes
- Battery gets warm

**Solutions:**

1. **Reduce Power Consumption**
   ```
   - Lower LED brightness: l80
   - Use lower magnet modes: 1 or 8
   - Reduce max duty: d70
   ```

2. **Check Battery Health**
   ```
   - Use higher capacity cells (3500mAh)
   - Check battery age (old batteries = less capacity)
   - Ensure all 4 cells are balanced
   ```

---

### Battery Won't Charge

**Symptoms:**
- No charging indicator
- Batteries don't charge via Micro-USB

**Solutions:**

1. **Check Charger**
   ```
   - Use 5V USB charger (1A-2A)
   - Try different charger
   - Check USB cable
   ```

2. **Check Battery Pack**
   ```
   - Verify Micro-USB port not damaged
   - Check charging LED indicator
   - May need to replace battery pack
   ```

---

## Still Having Issues?

### Get Help

1. **Check Documentation**
   - Read [README.md](README.md)
   - Review [WIRING.md](docs/WIRING.md)
   - Check [commands.md](commands.md)

2. **GitHub Issues**
   - Search existing issues
   - Create new issue with details:
     * Hardware setup
     * Firmware version
     * Serial Monitor output
     * Photos of wiring
     * What you've already tried

3. **Community Support**
   - MakerWorld: https://makerworld.com/en/crowdfunding/70-ferrowave
   - GitHub Discussions

---

**Project**: [FerroWave](https://github.com/matoslav/FerroWave)  
**Author**: Makarov87  
**Crowdfunded by**: MakerWorld Community

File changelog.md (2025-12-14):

# Changelog

All notable changes to FerroWave will be documented in this file.

The format is based on [Keep a Changelog](https://keepachangelog.com/en/1.0.0/),
and this project adheres to [Semantic Versioning](https://semver.org/spec/v2.0.0.html).

---

## [2.0.0] - 2024-12-14

### Added
- **AUX Input Support**: Auto-detection and manual switching for 3.5mm line input
- **Physical Button Controls**: Six onboard buttons for standalone operation
  - Buttons 1/2: Cycle magnet modes up/down
  - Buttons 3/4: Cycle LED modes up/down
  - Buttons 5/6: Cycle EQ presets up/down
- **8 EQ Presets**: Optimized audio profiles (Flat, Bass Boost, Treble, Vocal, Rock, Electronic, Jazz, Classical)
- **Battery Power System**: 4x18650 battery pack with 5V output
- **Breadboard Power Module**: Clean power distribution for all components
- Non-blocking button debouncing (200ms)
- Manual audio source switching via serial commands (`aux`, `bt`)
- Volume control via serial (`v<num>`)

### Changed
- **Power System**: Replaced USB-C PD trigger with 4x18650 battery system
  - Simpler wiring (single 5V rail)
  - Truly portable and cordless
  - 1-1.5 hours typical runtime
- **Performance**: Eliminated all blocking `delay()` calls
  - Fixed audio stuttering issues
  - Smooth 60fps LED updates
  - Responsive button handling
- **Startup**: Reduced LED animation delay from 720ms to 200ms
- **AUX Check Interval**: Increased from 500ms to 2000ms for efficiency
- Updated documentation for battery-powered design

### Fixed
- Audio stuttering caused by blocking delays in button handling
- LED blink on startup (reduced animation time)
- Naming conflict with AudioTools library (renamed enum to `InputSource`)
- Performance degradation from frequent AUX detection checks

### Documentation
- Complete rewrite of README.md with battery system
- New WIRING.md with 4x18650 setup
- New BOM.md (Bill of Materials)
- New CONTRIBUTING.md with crowdfunding acknowledgment
- New TROUBLESHOOTING.md with comprehensive solutions
- Updated LICENSE with MakerWorld crowdfunding attribution
- New commands.md with all serial commands documented

---

## [1.0.0] - 2024-11-XX

### Added
- **8 Magnet Behavior Modes**: SMOOTH, SPIKE, BOUNCE, CHAOS, PULSE, WAVE, TREMOLO, BREATH
- **10 LED Visual Effects**: Rainbow, Spectrum, VU-Meter, Pulse, Bass Glow, Fire, Ocean, Strobe, Chase, Sparkle
- **Serial Tuning Panel**: Live parameter adjustment via Serial Monitor
- **PWM Frequency Control**: Adjustable from 1-5000 Hz (`f<num>`)
- **Sensitivity Control**: 0-200% gain adjustment (`s<num>`)
- **Attack/Release Control**: Independent envelope shaping (`a<num>`, `r<num>`)
- **Duty Cycle Control**: Max and base duty settings (`d<num>`, `b<num>`)
- **Spike Intensity**: Extra boost for transient modes (`p<num>`)
- **LED Brightness Control**: 0-255 brightness levels (`l<num>`)
- **Test Pulse Command**: 2-second full-power test (`t`)
- **Status Commands**: Show settings (`?`), list modes (`m`, `n`)
- Bluetooth A2DP audio sink
- ES8388 audio codec support
- Multi-envelope audio analysis (fast, slow, peak, ultra-slow)
- MOSFET trigger module support with built-in flyback protection
- USB-C PD power support (later replaced with battery)

### Hardware
- ESP32-A1S Audio Kit v2.2 support
- WS2812B LED ring control (GPIO 23)
- Electromagnet PWM control (GPIO 22)
- AOD4184 MOSFET trigger module integration

### Documentation
- Initial README.md
- Serial commands reference
- Wiring instructions
- Preset recommendations

---

## [0.5.0] - 2024-10-XX (Pre-release)

### Added
- Basic ferrofluid control via Bluetooth audio
- Simple PWM electromagnet driving
- Basic LED strip support
- Prototype firmware testing

### Initial Concept
- ESP32-based audio reactive ferrofluid
- Breadboard prototype
- Manual parameter tuning in code

---

## Crowdfunding Campaign

**FerroWave was successfully crowdfunded on MakerWorld!**

Campaign: https://makerworld.com/en/crowdfunding/70-ferrowave

Special thanks to all backers who made this project possible. Your support brought FerroWave from concept to reality.

---

## Future Roadmap

### Planned for v2.1
- [ ] 3D-printable enclosure design
- [ ] Battery level indicator
- [ ] Power-saving sleep mode
- [ ] Preset save/load functionality
- [ ] OLED display for status

### Planned for v3.0
- [ ] Web interface for wireless configuration
- [ ] MIDI control support
- [ ] Multiple coil support (3D movement)
- [ ] Smartphone app
- [ ] Advanced audio analysis (FFT)

### Under Consideration
- [ ] Microphone input for acoustic response
- [ ] SD card for storing presets
- [ ] Real-time frequency analysis visualization
- [ ] Integration with music streaming services

---

## Version Numbering

FerroWave follows Semantic Versioning:

- **MAJOR** version: Incompatible hardware or API changes
- **MINOR** version: New features in backwards-compatible manner
- **PATCH** version: Backwards-compatible bug fixes

---

## Links

- **Repository**: https://github.com/matoslav/FerroWave
- **Crowdfunding**: https://makerworld.com/en/crowdfunding/70-ferrowave
- **Issues**: https://github.com/matoslav/FerroWave/issues
- **Discussions**: https://github.com/matoslav/FerroWave/discussions

---

**Project**: FerroWave  
**Author**: Makarov87  
**Crowdfunded by**: MakerWorld Community  
**License**: MIT

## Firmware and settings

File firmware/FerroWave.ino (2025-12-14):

/*
  FerroWave — Interactive Tuning with LED Ring + AUX Input + Button Controls

  NEW FEATURES:
  - AUX input auto-detection and switching
  - Six onboard buttons for live control:
    Button 1 (GPIO 36): Magnet mode UP (1-8)
    Button 2 (GPIO 39): Magnet mode DOWN (1-8)
    Button 3 (GPIO 34): LED mode UP (1-10)
    Button 4 (GPIO 35): LED mode DOWN (1-10)
    Button 5 (GPIO 32): EQ preset UP (8 presets)
    Button 6 (GPIO 33): EQ preset DOWN (8 presets)

  EQ PRESETS:
    0: Flat (neutral)
    1: Bass Boost (heavy bass, reduced treble)
    2: Treble (bright highs)
    3: Vocal (clear vocals)
    4: Rock (punchy)
    5: Electronic (EDM/Dance)
    6: Jazz (smooth)
    7: Classical (orchestra)

  WIRING:
    - MOSFET gate -> GPIO 22
    - LED ring DIN -> GPIO 23 (through 330Ω resistor recommended)
    - LED ring VCC -> 5V, GND -> GND
    - Buttons already wired on ESP32-A1S board

  SERIAL COMMANDS: (same as before)
    Magnet Mode Selection:
      1  -> SMOOTH mode (gentle flowing waves)
      2  -> SPIKE mode (sharp transients, spiky deformations)
      3  -> BOUNCE mode (rhythmic pumping)
      4  -> CHAOS mode (aggressive, unpredictable)
      5  -> PULSE mode (distinct on/off pulses with beats)
      6  -> WAVE mode (slow building waves, surging)
      7  -> TREMOLO mode (rapid flutter effect)
      8  -> BREATH mode (slow breathing, meditative)
    
    Tuning Parameters:
      f100   -> set PWM frequency to 100 Hz
      s50    -> set sensitivity/gain to 50 (0-200)
      a80    -> set attack speed to 80 (0-100)
      r20    -> set release speed to 20 (0-100)
      d60    -> set duty range to 60% (10-100)
      b20    -> set base duty to 20% (0-50)
      p30    -> set pulse/spike intensity to 30 (0-100)
      
    LED Control:
      l80    -> set LED brightness to 80 (0-255)
      c1     -> LED color mode (1-10)
      
    Audio Control:
      v75    -> set volume to 75 (0-100)
      eq1    -> bass EQ (-10 to +10)
      eq2    -> treble EQ (-10 to +10)
      aux    -> manually switch to AUX input
      bt     -> manually switch to Bluetooth
    
    Utilities:
      ?  -> show all current settings
      t  -> test pulse
      m  -> list all magnet modes
      n  -> list all LED modes
*/

#include <AudioTools.h>
#include <BluetoothA2DPSink.h>
#include <AudioTools/AudioLibs/AudioBoardStream.h>
#include <Adafruit_NeoPixel.h>

// ==== Magnet / PWM ====
const int  COIL_PIN         = 22;
const int  PWM_CH           = 1;
const int  PWM_RES          = 10;
const bool COIL_ACTIVE_HIGH = true;

// ==== LED Ring ====
const int LED_PIN       = 23;
const int LED_COUNT     = 24;
Adafruit_NeoPixel strip(LED_COUNT, LED_PIN, NEO_GRB + NEO_KHZ800);

uint8_t ledBrightness = 100;
uint8_t ledColorMode  = 1;

// ==== Button Pins (ESP32-A1S v2.2) ====
const int BTN_1 = 36;  // Key 1 - Cycle Magnet Mode
const int BTN_2 = 39;  // Key 2 - Cycle LED Mode
const int BTN_3 = 34;  // Key 3 - Volume Up (was 19 on some boards)
const int BTN_4 = 35;  // Key 4 - Volume Down (was 23 on some boards)
const int BTN_5 = 32;  // Key 5 - Bass EQ
const int BTN_6 = 33;  // Key 6 - Treble EQ

// Button debouncing
unsigned long lastBtnPress[6] = {0};
const unsigned long BTN_DEBOUNCE = 200;

// ==== Audio Source Selection ====
enum InputSource {
  SOURCE_BLUETOOTH,
  SOURCE_AUX
};

InputSource currentSource = SOURCE_BLUETOOTH;
bool auxPluggedIn = false;
unsigned long lastAuxCheckMs = 0;
const unsigned long AUX_CHECK_INTERVAL = 2000;  // Check every 2 seconds instead of 500ms

// ==== EQ Settings ====
int bassEQ = 0;    // -10 to +10
int trebleEQ = 0;  // -10 to +10
int volume = 80;   // 0-100

// Tunable parameters
float pwmFreqHz      = 4.0f;
float sensitivity    = 100.0f;
float attackSpeed    = 60.0f;
float releaseSpeed   = 30.0f;
float maxDuty        = 80.0f;
float baseDuty       = 15.0f;
float spikeIntensity = 50.0f;

float dutyPct = 0.0f;

// ==== Modes ====
enum VisualizationMode {
  MODE_SMOOTH  = 1,
  MODE_SPIKE   = 2,
  MODE_BOUNCE  = 3,
  MODE_CHAOS   = 4,
  MODE_PULSE   = 5,
  MODE_WAVE    = 6,
  MODE_TREMOLO = 7,
  MODE_BREATH  = 8
};

VisualizationMode currentMode = MODE_SMOOTH;

// ==== Audio pipeline ====
AudioBoard       board = AudioKitEs8388V1;
AudioBoardStream i2s_out(board);
RingBufferStream processing_stream(4096);
MultiOutput      duplicator;
BluetoothA2DPSink a2dp_sink(duplicator);

static const size_t SAMPLE_COUNT = 512;
int16_t sampleBuf[SAMPLE_COUNT];

// Envelope followers
float levelBlock = 0.0f;
float envSlow    = 0.0f;
float envFast    = 0.0f;
float envPeak    = 0.0f;
float envUltraSlow = 0.0f;

// State variables
float pulsePhase = 0.0f;
float waveAccumulator = 0.0f;
float tremoloOscillator = 0.0f;
unsigned long lastBeatMs = 0;

unsigned long nextDbgMs = 0;
unsigned long ledUpdateMs = 0;
float hue = 0.0f;
int chasePosition = 0;

// ==== Helper Functions ====

float clampf(float x, float lo, float hi) {
  return x < lo ? lo : (x > hi ? hi : x);
}

void applyPWM() {
  int dutyMax = (1 << PWM_RES) - 1;
  float d = clampf(dutyPct, 0.0f, 100.0f);
  
  if (!COIL_ACTIVE_HIGH) {
    d = 100.0f - d;
  }
  
  int dutyVal = (int)(d * dutyMax / 100.0f);
  dutyVal = constrain(dutyVal, 0, dutyMax);
  
  ledcWrite(PWM_CH, dutyVal);
}

void updatePWM() {
  ledcSetup(PWM_CH, pwmFreqHz, PWM_RES);
  ledcAttachPin(COIL_PIN, PWM_CH);
  applyPWM();
}

void applyEQ() {
  // Apply EQ settings to ES8388 codec
  // Bass: roughly corresponds to low frequency gain
  // Treble: high frequency gain
  board.setVolume(volume);
  
  // ES8388 has limited EQ control, but we can adjust tone
  // Note: Specific EQ implementation depends on AudioBoardStream capabilities
  Serial.printf("Volume: %d%%, Bass: %+d, Treble: %+d\n", volume, bassEQ, trebleEQ);
}

void switchToAUX() {
  if (currentSource == SOURCE_AUX) return;
  
  Serial.println("Switching to AUX input...");
  currentSource = SOURCE_AUX;
  
  // Configure board for line-in (AUX)
  board.setInputVolume(80);
  
  // On ES8388, we need to set input to AUX/Line-In
  // This is board-specific configuration
  Serial.println("AUX input active");
}

void switchToBluetooth() {
  if (currentSource == SOURCE_BLUETOOTH) return;
  
  Serial.println("Switching to Bluetooth...");
  currentSource = SOURCE_BLUETOOTH;
  Serial.println("Bluetooth active");
}

bool checkAUXConnected() {
  // The ES8388 can detect line-in signal presence
  // We'll check if there's a signal on the ADC input
  // This is a simplified check - adjust based on your board's capabilities
  
  // For now, we'll use a simple voltage detection approach
  // The AUX detection circuit varies by board design
  // Some boards have a detection pin, others require signal analysis
  
  // Placeholder: Check if processing stream has significant audio when BT is off
  // In practice, you might need a dedicated detection circuit or pin
  
  return false; // To be implemented based on your specific hardware
}

void checkAUXStatus() {
  if (millis() - lastAuxCheckMs < AUX_CHECK_INTERVAL) return;
  lastAuxCheckMs = millis();
  
  bool wasPluggedIn = auxPluggedIn;
  auxPluggedIn = checkAUXConnected();
  
  if (auxPluggedIn && !wasPluggedIn) {
    Serial.println("AUX cable detected!");
    switchToAUX();
  } else if (!auxPluggedIn && wasPluggedIn && currentSource == SOURCE_AUX) {
    Serial.println("AUX cable removed, switching to Bluetooth");
    switchToBluetooth();
  }
}

// ==== EQ Presets ====
struct EQPreset {
  const char* name;
  int bass;
  int treble;
  int volume;
};

const EQPreset eqPresets[] = {
  {"Flat",      0,   0,  80},  // 0: Neutral
  {"Bass Boost", 6,  -2,  75},  // 1: Heavy bass
  {"Treble",    -2,   6,  75},  // 2: Bright highs
  {"Vocal",      2,   4,  80},  // 3: Clear vocals
  {"Rock",       4,   3,  85},  // 4: Punchy rock
  {"Electronic", 5,   5,  80},  // 5: EDM/Dance
  {"Jazz",       1,   2,  75},  // 6: Smooth jazz
  {"Classical", -1,   1,  70}   // 7: Orchestra
};

const int NUM_EQ_PRESETS = 8;
int currentEQPreset = 0;

void applyEQPreset(int preset) {
  if (preset < 0 || preset >= NUM_EQ_PRESETS) return;
  
  bassEQ = eqPresets[preset].bass;
  trebleEQ = eqPresets[preset].treble;
  volume = eqPresets[preset].volume;
  
  applyEQ();
  Serial.printf("EQ Preset: %s (Bass:%+d Treb:%+d Vol:%d%%)\n", 
                eqPresets[preset].name, bassEQ, trebleEQ, volume);
}

// ==== Button Handling ====

void handleButtons() {
  unsigned long now = millis();
  
  // Button 1: Magnet Mode UP
  if (digitalRead(BTN_1) == LOW && (now - lastBtnPress[0]) > BTN_DEBOUNCE) {
    lastBtnPress[0] = now;
    int nextMode = (int)currentMode + 1;
    if (nextMode > 8) nextMode = 1;
    currentMode = (VisualizationMode)nextMode;
    Serial.printf("Button 1: Magnet UP -> %s\n", modeName());
  }
  
  // Button 2: Magnet Mode DOWN
  if (digitalRead(BTN_2) == LOW && (now - lastBtnPress[1]) > BTN_DEBOUNCE) {
    lastBtnPress[1] = now;
    int nextMode = (int)currentMode - 1;
    if (nextMode < 1) nextMode = 8;
    currentMode = (VisualizationMode)nextMode;
    Serial.printf("Button 2: Magnet DOWN -> %s\n", modeName());
  }
  
  // Button 3: LED Mode UP
  if (digitalRead(BTN_3) == LOW && (now - lastBtnPress[2]) > BTN_DEBOUNCE) {
    lastBtnPress[2] = now;
    ledColorMode++;
    if (ledColorMode > 10) ledColorMode = 1;
    Serial.printf("Button 3: LED UP -> %s\n", ledModeName());
  }
  
  // Button 4: LED Mode DOWN
  if (digitalRead(BTN_4) == LOW && (now - lastBtnPress[3]) > BTN_DEBOUNCE) {
    lastBtnPress[3] = now;
    ledColorMode--;
    if (ledColorMode < 1) ledColorMode = 10;
    Serial.printf("Button 4: LED DOWN -> %s\n", ledModeName());
  }
  
  // Button 5: EQ Preset UP
  if (digitalRead(BTN_5) == LOW && (now - lastBtnPress[4]) > BTN_DEBOUNCE) {
    lastBtnPress[4] = now;
    currentEQPreset++;
    if (currentEQPreset >= NUM_EQ_PRESETS) currentEQPreset = 0;
    applyEQPreset(currentEQPreset);
  }
  
  // Button 6: EQ Preset DOWN
  if (digitalRead(BTN_6) == LOW && (now - lastBtnPress[5]) > BTN_DEBOUNCE) {
    lastBtnPress[5] = now;
    currentEQPreset--;
    if (currentEQPreset < 0) currentEQPreset = NUM_EQ_PRESETS - 1;
    applyEQPreset(currentEQPreset);
  }
}

// ==== LED Functions ====

uint32_t HSVtoRGB(float h, float s, float v) {
  float r, g, b;
  
  int i = int(h * 6);
  float f = h * 6 - i;
  float p = v * (1 - s);
  float q = v * (1 - f * s);
  float t = v * (1 - (1 - f) * s);
  
  switch (i % 6) {
    case 0: r = v, g = t, b = p; break;
    case 1: r = q, g = v, b = p; break;
    case 2: r = p, g = v, b = t; break;
    case 3: r = p, g = q, b = v; break;
    case 4: r = t, g = p, b = v; break;
    case 5: r = v, g = p, b = q; break;
  }
  
  return strip.Color((uint8_t)(r * 255), (uint8_t)(g * 255), (uint8_t)(b * 255));
}

void updateLEDs() {
  float intensity = clampf(envFast, 0.0f, 1.0f);
  
  switch (ledColorMode) {
    case 1: // Rainbow spinning
      hue += 0.005f;
      if (hue > 1.0f) hue = 0.0f;
      for (int i = 0; i < LED_COUNT; i++) {
        float pixelHue = fmodf(hue + (float)i / LED_COUNT, 1.0f);
        uint32_t color = HSVtoRGB(pixelHue, 1.0f, intensity);
        strip.setPixelColor(i, color);
      }
      break;
      
    case 2: // Spectrum analyzer
      {
        int litLEDs = (int)(intensity * LED_COUNT);
        for (int i = 0; i < LED_COUNT; i++) {
          if (i < litLEDs) {
            float pixelHue = (float)i / LED_COUNT * 0.33f;
            uint32_t color = HSVtoRGB(pixelHue, 1.0f, 1.0f);
            strip.setPixelColor(i, color);
          } else {
            strip.setPixelColor(i, strip.Color(0, 0, 0));
          }
        }
      }
      break;
      
    case 3: // Single color pulse (blue)
      {
        uint32_t color = HSVtoRGB(0.6f, 1.0f, intensity);
        for (int i = 0; i < LED_COUNT; i++) {
          strip.setPixelColor(i, color);
        }
      }
      break;
      
    case 4: // VU meter (split middle)
      {
        int litLEDs = (int)(intensity * (LED_COUNT / 2));
        for (int i = 0; i < LED_COUNT; i++) {
          int dist = abs(i - LED_COUNT / 2);
          if (dist <= litLEDs) {
            float pixelHue = (float)dist / (LED_COUNT / 2) * 0.33f;
            uint32_t color = HSVtoRGB(pixelHue, 1.0f, 1.0f);
            strip.setPixelColor(i, color);
          } else {
            strip.setPixelColor(i, strip.Color(0, 0, 0));
          }
        }
      }
      break;
      
    case 5: // Bass glow (red when loud)
      {
        float bassGlow = envSlow * 2.0f;
        bassGlow = clampf(bassGlow, 0.0f, 1.0f);
        uint32_t color = HSVtoRGB(0.0f, 1.0f, bassGlow);
        for (int i = 0; i < LED_COUNT; i++) {
          strip.setPixelColor(i, color);
        }
      }
      break;
      
    case 6: // Fire effect
      {
        for (int i = 0; i < LED_COUNT; i++) {
          float flicker = 0.7f + (random(30) / 100.0f);
          float heat = intensity * flicker;
          uint32_t color = HSVtoRGB(0.05f, 1.0f, heat);
          strip.setPixelColor(i, color);
        }
      }
      break;
      
    case 7: // Ocean waves (blue-green)
      {
        hue += 0.002f;
        if (hue > 1.0f) hue = 0.0f;
        for (int i = 0; i < LED_COUNT; i++) {
          float wave = sin((hue + (float)i / LED_COUNT) * 6.28f) * 0.5f + 0.5f;
          float pixelHue = 0.5f + wave * 0.15f;
          uint32_t color = HSVtoRGB(pixelHue, 1.0f, intensity * 0.8f + 0.2f);
          strip.setPixelColor(i, color);
        }
      }
      break;
      
    case 8: // Strobe flash
      {
        if (intensity > 0.7f) {
          for (int i = 0; i < LED_COUNT; i++) {
            strip.setPixelColor(i, strip.Color(255, 255, 255));
          }
        } else {
          strip.clear();
        }
      }
      break;
      
    case 9: // Color chase
      {
        if (intensity > 0.5f) {
          chasePosition = (chasePosition + 1) % LED_COUNT;
        }
        strip.clear();
        for (int i = 0; i < 3; i++) {
          int pos = (chasePosition + i * 8) % LED_COUNT;
          uint32_t color = HSVtoRGB((float)i / 3.0f, 1.0f, intensity);
          strip.setPixelColor(pos, color);
        }
      }
      break;
      
    case 10: // Sparkle
      {
        strip.clear();
        int numSparkles = (int)(intensity * 8);
        for (int i = 0; i < numSparkles; i++) {
          int pos = random(LED_COUNT);
          uint32_t color = HSVtoRGB(random(100) / 100.0f, 1.0f, 1.0f);
          strip.setPixelColor(pos, color);
        }
      }
      break;
  }
  
  strip.show();
}

// ==== Mode Names ====

const char* modeName() {
  switch (currentMode) {
    case MODE_SMOOTH:  return "SMOOTH";
    case MODE_SPIKE:   return "SPIKE";
    case MODE_BOUNCE:  return "BOUNCE";
    case MODE_CHAOS:   return "CHAOS";
    case MODE_PULSE:   return "PULSE";
    case MODE_WAVE:    return "WAVE";
    case MODE_TREMOLO: return "TREMOLO";
    case MODE_BREATH:  return "BREATH";
    default:           return "UNKNOWN";
  }
}

const char* ledModeName() {
  switch (ledColorMode) {
    case 1:  return "Rainbow";
    case 2:  return "Spectrum";
    case 3:  return "Pulse";
    case 4:  return "VU-Meter";
    case 5:  return "Bass Glow";
    case 6:  return "Fire";
    case 7:  return "Ocean";
    case 8:  return "Strobe";
    case 9:  return "Chase";
    case 10: return "Sparkle";
    default: return "Unknown";
  }
}

// ==== Serial Commands ====

void printSettings() {
  Serial.println(F("\n========== CURRENT SETTINGS =========="));
  Serial.printf("Audio Source:    %s\n", currentSource == SOURCE_BLUETOOTH ? "Bluetooth" : "AUX");
  Serial.printf("Magnet Mode:     %s\n", modeName());
  Serial.printf("PWM Frequency:   %.1f Hz\n", pwmFreqHz);
  Serial.printf("Sensitivity:     %.0f%%\n", sensitivity);
  Serial.printf("Attack Speed:    %.0f/100\n", attackSpeed);
  Serial.printf("Release Speed:   %.0f/100\n", releaseSpeed);
  Serial.printf("Max Duty:        %.0f%%\n", maxDuty);
  Serial.printf("Base Duty:       %.0f%%\n", baseDuty);
  Serial.printf("Spike Intensity: %.0f/100\n", spikeIntensity);
  Serial.printf("Volume:          %d%%\n", volume);
  Serial.printf("EQ Preset:       %s\n", eqPresets[currentEQPreset].name);
  Serial.printf("Bass EQ:         %+d\n", bassEQ);
  Serial.printf("Treble EQ:       %+d\n", trebleEQ);
  Serial.printf("LED Brightness:  %d/255\n", ledBrightness);
  Serial.printf("LED Mode:        %s\n", ledModeName());
  Serial.println(F("======================================\n"));
}

void printHelp() {
  Serial.println(F("\n========== COMMANDS =========="));
  Serial.println(F("Magnet: 1-8 | LED: c1-c10"));
  Serial.println(F("Tuning: f<Hz> s<sens> a<atk> r<rel>"));
  Serial.println(F("        d<duty> b<base> p<spike>"));
  Serial.println(F("Audio:  v<vol> eq1<bass> eq2<treb>"));
  Serial.println(F("        aux (switch) bt (switch)"));
  Serial.println(F("LED:    l<brightness>"));
  Serial.println(F("Utils:  ? (settings) m (modes)"));
  Serial.println(F("        n (LED) t (test)"));
  Serial.println(F("==============================\n"));
}

void testPulse() {
  Serial.println(F("TEST PULSE: 2 seconds at max..."));
  dutyPct = maxDuty;
  applyPWM();
  
  for (int i = 0; i < LED_COUNT; i++) {
    strip.setPixelColor(i, strip.Color(255, 255, 255));
  }
  strip.show();
  
  delay(2000);
  
  dutyPct = baseDuty;
  applyPWM();
  strip.clear();
  strip.show();
  
  Serial.println(F("Test complete.\n"));
}
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
void loop() {
  handleSerial();
  handleButtons();
  checkAUXStatus();

  size_t avail = processing_stream.available();

  if (avail >= SAMPLE_COUNT * sizeof(int16_t)) {
    size_t got = processing_stream.readBytes((uint8_t*)sampleBuf,
                                             SAMPLE_COUNT * sizeof(int16_t));
    if (got == SAMPLE_COUNT * sizeof(int16_t)) {
      double acc = 0.0;
      for (size_t i = 0; i < SAMPLE_COUNT; i++) {
        float v = sampleBuf[i] / 32768.0f;
        acc += v * v;
      }
      levelBlock = sqrtf(acc / SAMPLE_COUNT);

      calculateDuty();
      applyPWM();

      if (millis() - ledUpdateMs >= 16) {
        updateLEDs();
        ledUpdateMs = millis();
      }

      if (millis() >= nextDbgMs) {
        Serial.printf("[%s/%s/%s] lvl=%.3f duty=%.1f%% vol=%d%%\n",
                      currentSource == SOURCE_BLUETOOTH ? "BT" : "AUX",
                      modeName(), ledModeName(), levelBlock, dutyPct, volume);
        nextDbgMs = millis() + 300;
      }
    }
  } else {
    envFast *= 0.98f;
    envSlow *= 0.98f;
    envPeak *= 0.95f;
    envUltraSlow *= 0.99f;
    
    if (envSlow < 0.01f) {
      dutyPct = 0.0f;
    } else {
      calculateDuty();
    }
    applyPWM();
    
    if (millis() - ledUpdateMs >= 16) {
      updateLEDs();
      ledUpdateMs = millis();
    }
    
    delay(5);
  }
}

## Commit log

2025-12-14 Create wiring
2025-12-14 3d print files upload
    [Back Circle.stl, Back panel left.stl, Back panel right.stl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]
2025-12-25 Create Aqarion_bootstrap.aqa
    NOW PROD7CE ALL THIS AS PROFESIONAL INTRIGUING BOOTSTRAP EDITION FOR ALL PUBLIC REPOS...... GO ALL OUT HERE ILL POST ASAP
    https://www.facebook.com/share/v/1A4eidTCpP/
    @Aqarion13, Instagram
    @NVS1991SNV,X
    https://www.linkedin.com/posts/aqarion-j-aaron-91125a391_james-aaron-activity-7409956979068018689-FWd2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
    https://www.threads.com/@aqarionz13/post/DSsGXppAKN3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
